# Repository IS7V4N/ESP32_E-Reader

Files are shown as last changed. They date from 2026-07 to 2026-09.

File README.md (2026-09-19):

# ESP32 E-Reader

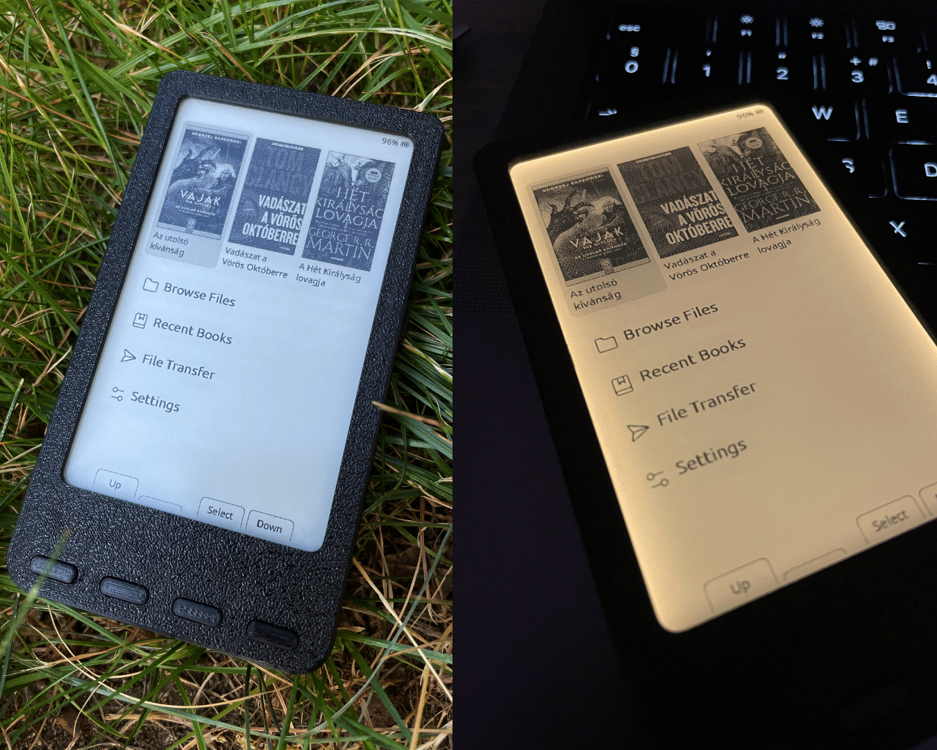
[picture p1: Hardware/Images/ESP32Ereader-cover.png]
ESP32 E-reader


A custom-built e-ink reading device based on the ESP32-C3, designed for everyday use. Built around a 4.2" e-ink display with a frontlight for reading in the dark environment, running a modified version of the [Crosspoint](https://github.com/crosspoint-reader/crosspoint-reader) open-source firmware adapted for custom hardware. The goal was to build a capable, low-cost alternative to commercial e-readers with full control over both hardware and software.

---
## Hardware License

The hardware designs in `/Hardware` are licensed under the
[CERN-OHL-W v2](Hardware/LICENSE).

## Hardware

> Building your own? See the [Build guide](Hardware/docs/Build%20guide.md) for step-by-step assembly instructions.

| Component  | Details |
| --- | --- |
| MCU | ESP32-C3 (4MB flash) |
| Display | Good Display 4.2" grayscale e-ink panel |
| Storage | SD card (books, cache, user settings) |
| Frontlight | TI TPS61169 PWM-controlled LED driver, 15V boost |
| Battery | 700mAh LiPo |
| USB | USB-C (charging + native USB via differential pair) |
| PCB | 4-layer, custom KiCad design (Rev. B) |

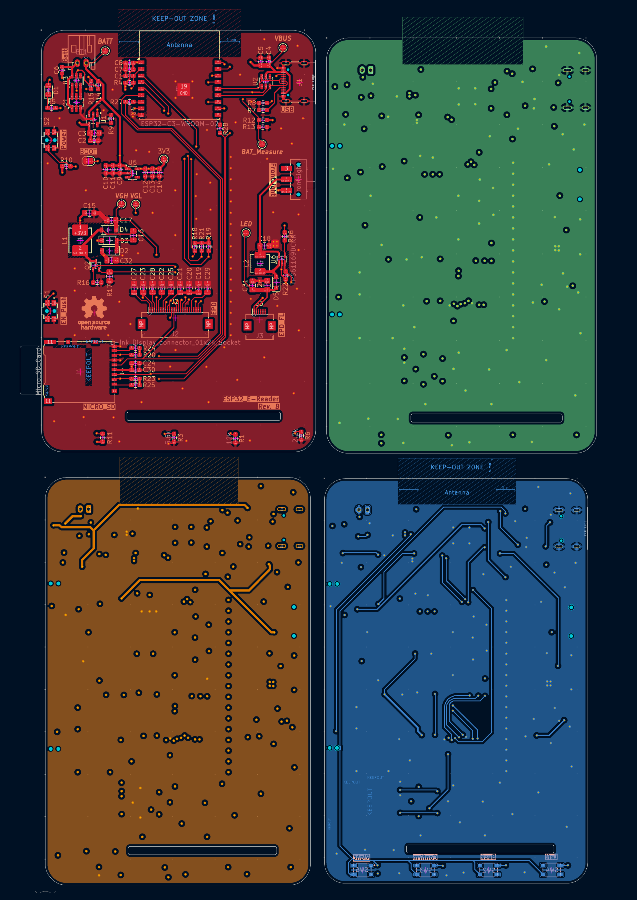
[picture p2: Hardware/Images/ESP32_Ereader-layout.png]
PCB layout


### PCB stack-up

```
F.Cu     — signal
GND      — full ground plane
PWR      — power distribution
B.Cu     — signal
```

Ground pour with stitching vias on both outer layers. EMI-sensitive boost converter traces kept compact.

### Power rails

| Rail | Source | Purpose |
| --- | --- | --- |
| 3.4–4.2V | LiPo battery | System input |
| 3.3V | LDO | ESP32-C3, logic |
| 5V | USB-C input | Charging |
| ±20V | Boost converter | E-ink panel driver |
| 15V | Boost converter (TPS61169) | Frontlight LED driver |

### Power management

Three operating states optimized for battery life:

| State | Description | Wake latency |
| --- | --- | --- |
| Active | Full speed, display updating | — |
| Sleep | Reduced CPU clock, peripherals idle | Fast |
| Deep sleep | µA range consumption, triggered by power button | Slow |

The device enters Sleep automatically after a display update completes. Deep sleep is only used when powered off via the power button.

### Controls

| Button | Function |
| --- | --- |
| Left / Right / Back / Confirm | Context-sensitive navigation (current function shown on display) |
| Power button | Short press: page turn / Long press: power on/off |

---

## Firmware

Based on [Crosspoint Reader](https://github.com/crosspoint-reader/crosspoint-reader) with modifications for custom hardware and 4MB flash constraint.

### What's changed from upstream

- **HalFrontlight** — new HAL driver for PWM-controlled frontlight via TPS61169
- **HalPowerManager** — smaller tweaks
- **HalGPIO** — GPIO, button layout adapted to custom PCB
- **partitions_4mb.csv** — custom partition scheme to fit 4MB flash (replaces upstream 16MB default)
- **platformio.ini** — 4MB build configuration
- **Display refresh** — modified refresh handling for Good Display 4.2" panel compatibility
- **Dictionary** — English → Hungarian word lookup in the EPUB reader (see [Dictionary](#dictionary))

See [`docs/4mb-build/`](Software/crosspoint-reader/docs/4mb-build/) for detailed documentation on the 4MB build process and known issues.

## Dictionary

Long-press **Confirm** (0.5 s) in an EPUB to enter dictionary mode. The four front buttons become a cursor:

| Button (left to right) | Short press  | Long press |
| --- | --- | --- |
| Left | cursor left  | — |
| Back | cursor up | leave dictionary mode |
| Confirm | cursor down  | translate the selected word |
| Right | cursor right | — |

The translation (a few Hungarian words) appears in a popup, any button closes it.

The dictionary is a file on the SD card, `/dict/en-hu.dic` (about 4 MB, 118 000 word forms incl. inflections). It is
built on a PC with [`scripts/build_dict.py`](Software/crosspoint-reader/scripts/build_dict.py) from Wiktionary
(via [kaikki.org](https://kaikki.org)) with [FreeDict eng-hun](https://freedict.org) as a fallback; the script
documents the steps and the file format. Wiktionary data is CC BY-SA 4.0, FreeDict eng-hun is GPL-2.0+.

---

## Repository structure

```
ESP32_E-Reader/
├── Hardware/
│   ├── 3D CAD/                 — enclosure 3D models
│   ├── Bill Of Materials/      — BOM spreadsheets
│   ├── PCB/                    — KiCad project (Rev. B)
│   ├── REV-A/                  — Rev. A schematic/layout reference
│   └── LICENSE                 — CERN-OHL-W v2
├── Datasheets of Components/    — component datasheets (PDF)
└── Software/
    └── crosspoint-reader/       — firmware (fork of Crosspoint Reader)
        ├── src/                 — application source (activities, UI)
        ├── lib/                 — internal libraries (Epub engine, GfxRenderer, HAL, I18n)
        ├── open-x4-sdk/         — Xteink X4 community SDK (submodule)
        ├── docs/                — build docs, file formats, 4mb-build notes
        ├── scripts/             — build/codegen/debugging scripts
        ├── test/                — unit tests
        ├── platformio.ini       — build configuration
        └── LICENSE              — MIT
```

---

## Build

### Requirements

- [PlatformIO](https://platformio.org/)
- ESP32-C3 board with 4MB flash

### Steps

```bash
git clone https://github.com/IS7V4N/ESP32_E-Reader.git
cd ESP32_E-Reader
git submodule update --init --recursive
~/.platformio/penv/bin/pio run -e 4mb -t upload
```

---

## License
`/Hardware` are licensed under the
[CERN-OHL-W v2](Hardware/LICENSE).

Firmware modifications follow the license of the upstream [Crosspoint Reader](https://github.com/crosspoint-reader/crosspoint-reader) project.

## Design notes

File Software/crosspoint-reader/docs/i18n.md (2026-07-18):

# This version of the firmware DOES NOT INCLUDE

# Internationalization (I18N)

This guide explains the multi-language support system in CrossPoint Reader.

## Supported Languages

- English
- French
- German
- Portuguese
- Spanish
- Swedish
- Czech
- Russian
- Ukrainian
- Polish
- Danish
- Turkish

---

## For Developers

### Translation System Architecture

The I18N system uses **per-language YAML files** to maintain translations and a Python script to generate C++ code:

```
lib/I18n/
├── translations/                # One YAML file per language
│   ├── english.yaml
│   ├── spanish.yaml
│   ├── french.yaml
│   └── ...
├── I18n.h
├── I18n.cpp
├── I18nKeys.h                   # Enums (auto-generated)
├── I18nStrings.h                # String array declarations (auto-generated)
└── I18nStrings.cpp              # String array definitions (auto-generated)

scripts/
└── gen_i18n.py                  # Code generator script
```

**Key principle:** All translations are managed in the YAML files under `lib/I18n/translations/`. The Python script generates the necessary C++ code automatically.

---

### YAML File Format

Each language has its own file in `lib/I18n/translations/` (e.g. `spanish.yaml`).

A file looks like this:

```yaml
_language_name: "Español"
_language_code: "ES"
_order: "1"

STR_CROSSPOINT: "CrossPoint"
STR_BOOTING: "BOOTING"
STR_BROWSE_FILES: "Buscar archivos"
```

**Metadata keys** (prefixed with `_`):
- `_language_name` — Native display name shown to the user (e.g. "Français")
- `_language_code` — C++ enum name (e.g. "FR"). Please use the [ISO Code](https://en.wikipedia.org/wiki/List_of_ISO_639_language_codes) of the language. Must be a valid C++ identifier.
- `_order` — Controls the position in the Language enum (English is always 0)

**Rules:**
- Use UTF-8 encoding
- Every line must follow the format: `KEY: "value"`
- Keys must be valid C++ identifiers (uppercase, starts with STR_)
- Keys must be unique within a file
- String values must be quoted
- Use `\n` for newlines, `\\` for literal backslashes, `\"` for literal quotes inside values

---

### Adding New Strings

To add a new translatable string:

#### 1. Edit the English YAML file

Add the key to `lib/I18n/translations/english.yaml`:

```yaml
STR_MY_NEW_STRING: "My New String"
```

Then add translations in each language file. If a key is missing from a
language file, the generator will automatically use the English text as a
fallback (and print a warning).

#### 2. Run the generator script

```bash
python3 scripts/gen_i18n.py lib/I18n/translations lib/I18n/
```

This automatically:
- Fills missing translations from English
- Updates the `StrId` enum in `I18nKeys.h`
- Regenerates all language arrays in `I18nStrings.cpp`

#### 3. Use in code

```cpp
#include <I18n.h>

// Using the tr() macro (recommended)
renderer.drawText(font, x, y, tr(STR_MY_NEW_STRING));

// Using I18N.get() directly
const char* text = I18N.get(StrId::STR_MY_NEW_STRING);
```

**That's it!** No manual array synchronization needed.

---

### Adding a New Language

To add support for a new language (e.g., Italian):

#### 1. Create a new YAML file

Create `lib/I18n/translations/italian.yaml`:

```yaml
_language_name: "Italiano"
_language_code: "IT"
_order: "7"

STR_CROSSPOINT: "CrossPoint"
STR_BOOTING: "AVVIO"
```

You only need to include the strings you have translations for. Missing
keys will fall back to English automatically.

#### 2. Run the generator

```bash
python3 scripts/gen_i18n.py lib/I18n/translations lib/I18n/
```

This automatically updates all necessary code.

---

### Modifying Existing Translations

Simply edit the relevant YAML file and regenerate:

```bash
python3 scripts/gen_i18n.py lib/I18n/translations lib/I18n/
```

---

### UTF-8 Encoding

The YAML files use UTF-8 encoding. Special characters are automatically converted to C++ UTF-8 hex sequences by the generator.

---

### I18N API Reference

```cpp
// === Convenience Macros (Recommended) ===

// tr(id) - Get translated string without StrId:: prefix
const char* text = tr(STR_SETTINGS_TITLE);
renderer.drawText(font, x, y, tr(STR_BROWSE_FILES));
Serial.printf("Status: %s\n", tr(STR_CONNECTED));

// I18N - Shorthand for I18n::getInstance()
I18N.setLanguage(Language::ES);
Language lang = I18N.getLanguage();

// === Full API ===

// Get the singleton instance
I18n& instance = I18n::getInstance();

// Get translated string (three equivalent ways)
const char* text = tr(STR_SETTINGS_TITLE);              // Macro (recommended)
const char* text = I18N.get(StrId::STR_SETTINGS_TITLE);   // Direct call
const char* text = I18N[StrId::STR_SETTINGS_TITLE];       // Operator overload

// Set language
I18N.setLanguage(Language::ES);

// Get current language
Language lang = I18N.getLanguage();

// Save language setting to file
I18N.saveSettings();

// Load language setting from file
I18N.loadSettings();

// Get character set for font subsetting (static method)
const char* chars = I18n::getCharacterSet(Language::FR);
```

---

## File Storage

Language settings are stored in:
```
/.crosspoint/language.bin
```

This file contains:
- Version byte
- Current language selection (1 byte)

---

## Translation Workflow

### For Developers (Adding Features)

1. Add new strings to `lib/I18n/translations/english.yaml`
2. Run `python3 scripts/gen_i18n.py lib/I18n/translations lib/I18n/`
3. Use the new `StrId` in your code
4. Request translations from translators

### For Translators

1. Open the YAML file for your language in `lib/I18n/translations/`
2. Add or update translations using the format `STR_KEY: "translated text"`
3. Keep translations concise (E-ink space constraints)
4. Make sure the file is in UTF-8 encoding
5. Run `python3 scripts/gen_i18n.py lib/I18n/translations lib/I18n/` to verify
6. Test on device or submit for review

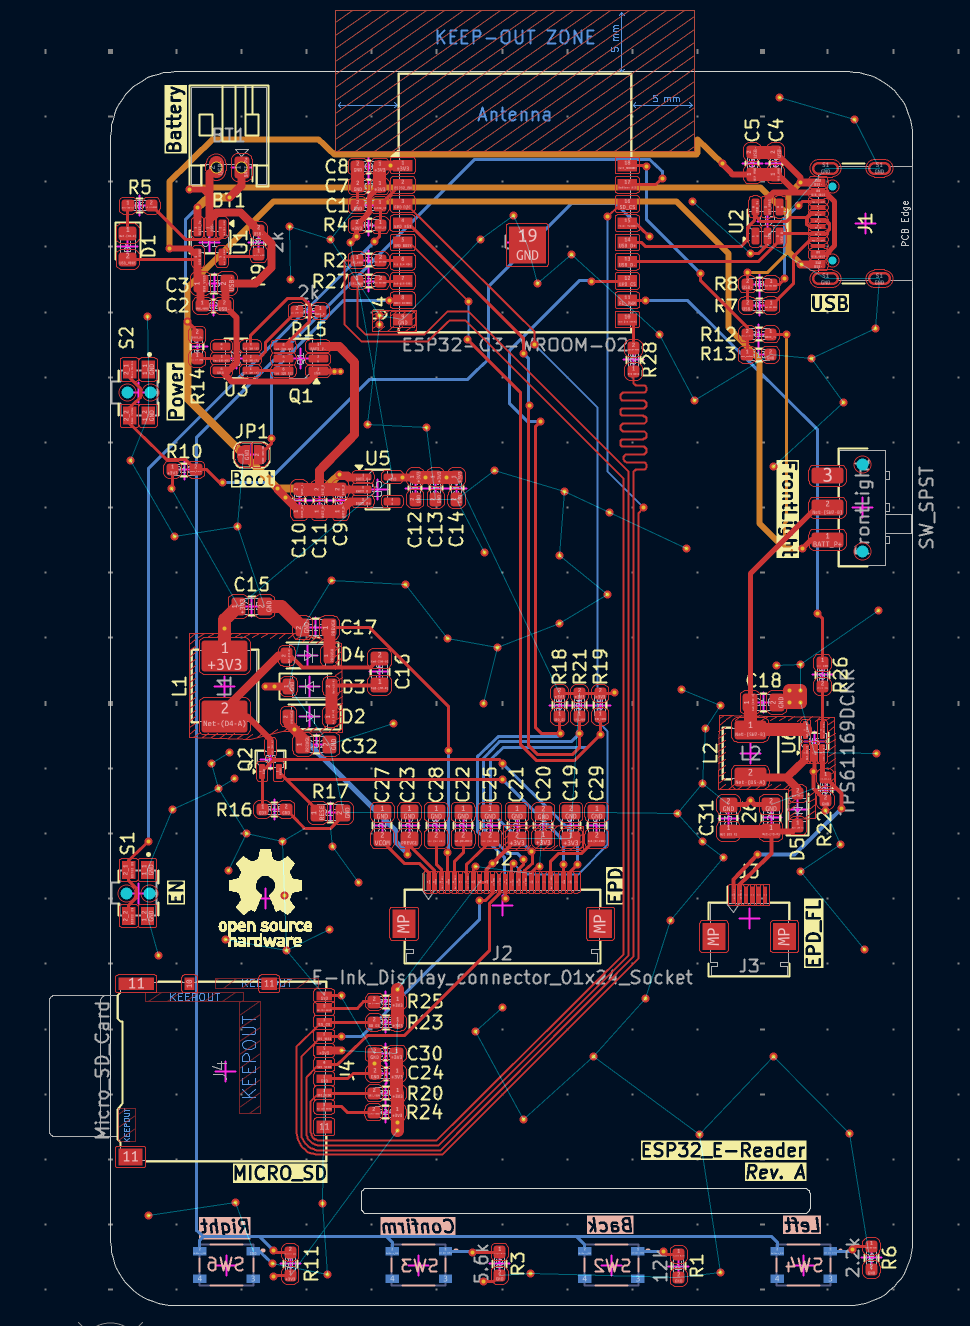
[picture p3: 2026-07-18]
Hardware/REV-A/Rev-A_layout.png

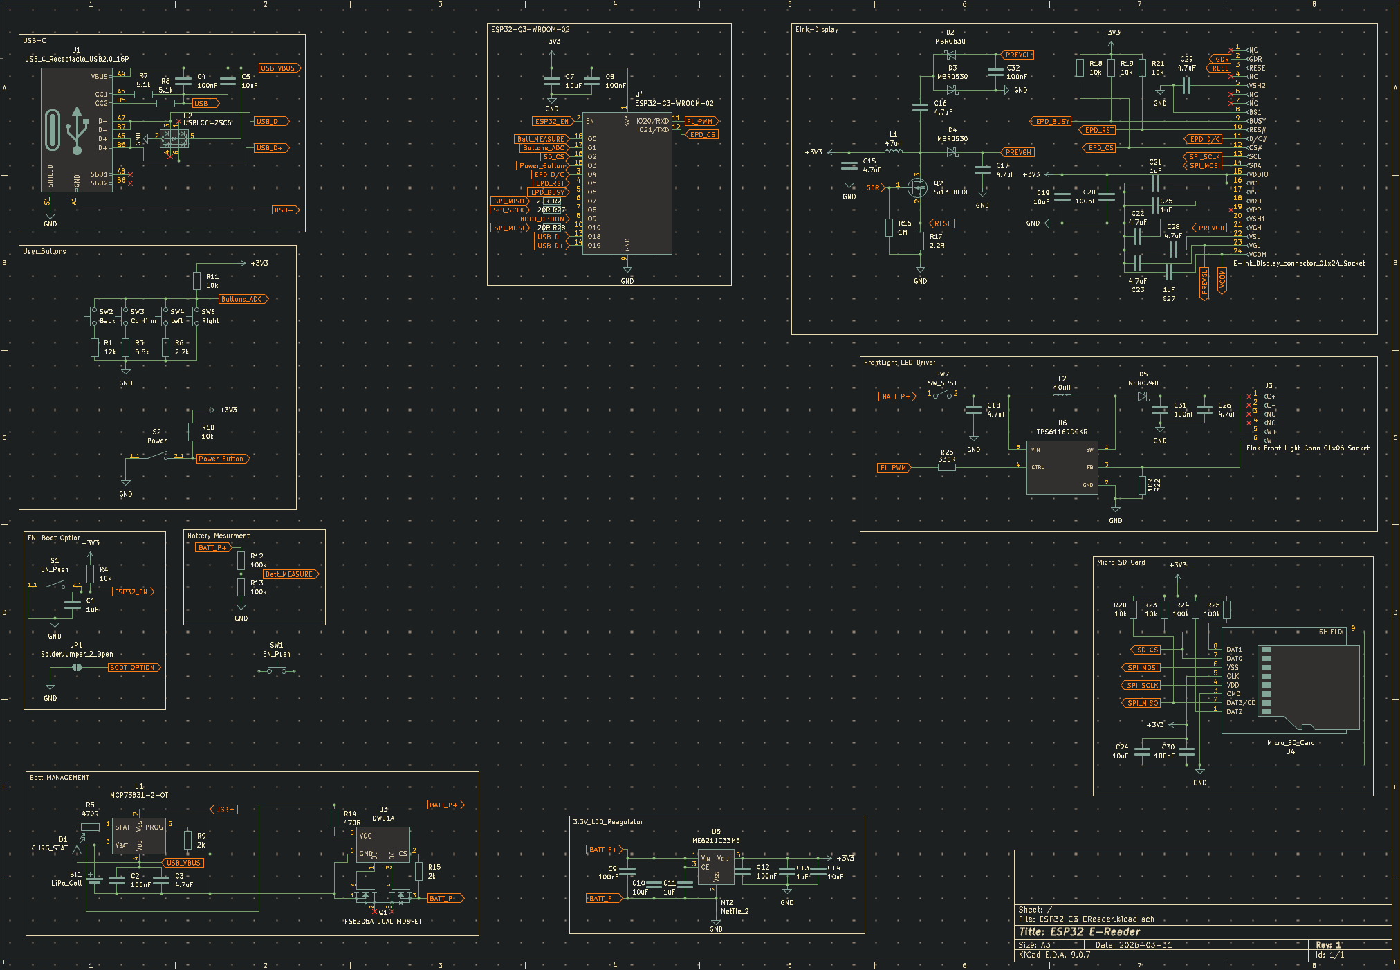
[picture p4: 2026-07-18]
Hardware/REV-A/Rev-A_Schem.png

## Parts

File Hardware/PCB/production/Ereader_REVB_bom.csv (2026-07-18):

Designator | Footprint | Quantity | Value | LCSC Part #
BT1 | JST_PH_S2B-PH-K_1x02_P2.00mm_Horizontal | 1 | Batt
C1, C11, C13 | 0603 | 3 | 1uF
C10, C14, C24, C5, C6, C7 | 0603 | 6 | 10uF
C12, C2, C30, C4, C8, C9 | 0603 | 6 | 100nF
C15, C16, C17, C18, C22, C23, C26, C28, C29, C3 | 0805 | 10 | 4.7uF
C19 | 0805 | 1 | 10uF
C20, C31, C32 | 0805 | 3 | 100nF
C21, C25, C27 | 0805 | 3 | 1uF
D1 | 0805 | 1 | CHRG_STAT
D2, D3, D4 | D_SOD-123 | 3 | MBR0530
D5 | D_SOD-323_HandSoldering | 1 | NSR0240
FRONTLIGHT | SW_SPDT_CK_JS102011SAQN | 1 | EPD_FL
J1 | USB_C_Receptacle_GCT_USB4105-xx-A_16P_TopMnt_Horizontal | 1 | USB
J2 | Mirrored_Hirose_FH12-24S-0.5SH_1x24-1MP_P0.50mm_Horizontal | 1 | E-Ink_Display_connector_01x24_Socket
J3 | XUNPU FPC-05FB-6PH20_1x06-1MP_P0.50mm_Horizontal | 1 | EInk_Front_Light_Conn_01x06_Socket
J4 | microSD_HC_Hirose_DM3AT-SF-PEJM5 | 1 | Micro_SD_Card
L1 | L_Panasonic_PCC-M0540M | 1 | 47uH
L2 | L_Changjiang_FXL0420 | 1 | 10uH
Q1 | SOT-23-6_Handsoldering | 1 | FS8205A_DUAL_MOSFET
Q2 | SOT-323_SC-70 | 1 | Si1308EDL
R1 | 0603 | 1 | 12k
R10, R11, R18, R19, R20, R21, R23, R4 | 0603 | 8 | 10k
R12, R13, R24, R25 | 0603 | 4 | 100k
R14, R5 | 0603 | 2 | 470R
R15 | 0603 | 1 | 2.7k
R16 | 0603 | 1 | 1M
R17 | 0805 | 1 | 2.2R
R22 | 0603 | 1 | 10R
R26 | 0603 | 1 | 330R
R27, R28 | 0603 | 2 | 20R
R3 | 0603 | 1 | 5.6k
R6 | 0603 | 1 | 2.2k
R7, R8 | 0603 | 2 | 5.1k
R9 | 0603 | 1 | 2.5k
S1 | SW_EVQ-P7C01P | 1 | EN_Push
S2 | SW_EVQ-P7C01P | 1 | Power
SW2 | SW_SKRPACE010 | 1 | Back
SW3 | SW_SKRPACE010 | 1 | Confirm
SW4 | SW_SKRPACE010 | 1 | Left
SW6 | SW_SKRPACE010 | 1 | Right
TP1 | TestPoint_Pad_D1.5mm | 1 | BATT
TP2 | TestPoint_Pad_D1.5mm | 1 | 3V3
TP3 | TestPoint_Pad_D1.5mm | 1 | VBUS
TP4 | TestPoint_Pad_D1.5mm | 1 | VGL
TP5 | TestPoint_Pad_D1.5mm | 1 | VGH
TP6 | TestPoint_Pad_D1.5mm | 1 | BAT_Measure
TP7 | TestPoint_Pad_D1.5mm | 1 | LED
U1 | SOT-23-5 | 1 | MCP73831-2-OT
U2 | SOT-23-6 | 1 | USBLC6-2SC6
U3 | SOT-23-6 | 1 | DW01A
U4 | ESP32-C3-WROOM-02 | 1 | ESP32-C3-WROOM-02
U5 | SOT-23-5 | 1 | ME6211C33M5
U6 | SOT-353_SC-70-5 | 1 | TPS61169DCKR

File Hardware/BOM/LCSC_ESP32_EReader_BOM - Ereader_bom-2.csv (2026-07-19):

Designator | Footprint | Quantity | Value | LCSC Part # | Comment
BT1 | JST_PH_S2B-PH-K_1x02_P2.00mm_Horizontal | 1 | LiPo_Cell | C173752
C1, C11, C13 | 603 | 3 | 1uF | C29936
C10, C14, C24, C5, C7 | 603 | 5 | 10uF | C96446
C12, C2, C30, C4, C8, C9 | 603 | 6 | 100nF | C14663
C15, C16, C17, C18, C22, C23, C26, C28, C29, C3 | 805 | 10 | 4.7uF | C1779
C19 | 805 | 1 | 10uF | C3039694
C21, C25, C27 | 805 | 3 | 1uF | C28323
D2, D3, D4 | D_SOD-123 | 3 | MBR0530 | C82046
D5 | D_SOD-323 | 1 | NSR0240 | C152519 | ordered PMEG4005EJ,115 C426868 (because of long lead time)
J2 | Mirrored_Hirose_FH12-24S-0.5SH_1x24-1MP_P0.50mm_Horizontal | 1 | E-Ink_Display_connector_01x24_Socket | C2856831
J3 | XUNPU FPC-05FB-6PH20_1x06-1MP_P0.50mm_Horizontal | 1 | EInk_Front_Light_Conn_01x06_Socket | C2856827
J4 | microSD_HC_Hirose_DM3AT-SF-PEJM5 | 1 | Micro_SD_Card | C114218
L1 | L_Panasonic_PCC-M0540M | 1 | 47uH | C520357
L2 | L_Changjiang_FXL0420 | 1 | 10uH | C520308
Q1 | SOT-23-6_Handsoldering | 1 | FS8205A_DUAL_MOSFET | C2830320
Q2 | SOT-323_SC-70 | 1 | Si1308EDL | C469327
R1 | 603 | 1 | 12k | C114659
R10, R11, R18, R19, R20, R21, R23, R4 | 603 | 8 | 10k | C98220
R12, R13, R24, R25 | 603 | 4 | 100k | C14675
R14, R5 | 603 | 2 | 470R | C114669
R15, R9 | 603 | 2 | 2k | C22975
R16 | 603 | 1 | 1M | C105578
R17 | 805 | 1 | 2.2R | C2907006
R2, R27, R28 | 603 | 3 | 20R | C125758
R22 | 603 | 1 | 10R | C109318
R26 | 603 | 1 | 330R | C105881
R3 | 603 | 1 | 5.6k | C114627
R6 | 603 | 1 | 2.2k | C113303
R7, R8 | 603 | 2 | 5.1k | C105580
S1 | SW_EVQ-P7C01P | 1 | EN_Push | C388883
S2 | SW_EVQ-P7C01P | 1 | Power | C139797
SW2 | SW_SKRPACE010 | 1 | Back | C139797
SW3 | SW_SKRPACE010 | 1 | Confirm | C139797
SW4 | SW_SKRPACE010 | 1 | Left | C139797
SW6 | SW_SKRPACE010 | 1 | Right | C139797
SW7 | SW_SPDT_CK_JS102011SAQN | 1 | SW_SPST | C49023765
U1 | SOT-23-5 | 1 | MCP73831-2-OT | C424093
U2 | SOT-23-6 | 1 | USBLC6-2SC6 | C7519
U3 | SOT-23-6 | 1 | DW01A | C2927799
U4 | ESP32-C3-WROOM-02 | 1 | ESP32-C3-WROOM-02 | C2934560
U5 | SOT-23-5 | 1 | ME6211C33M5 | C82942
U6 | SOT-353_SC-70-5 | 1 | TPS61169DCKR | C71045
 |  | 81

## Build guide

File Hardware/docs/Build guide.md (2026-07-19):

# Build Guide

This guide walks through assembling the ESP32 E-Reader from a bare PCB to a working device: soldering, enclosure printing, firmware flashing, and first boot.

---

## 1. Get the PCB made

Order the PCB from [JLCPCB](https://jlcpcb.com/) using the Gerbers in [`Hardware/PCB/production`](../PCB/production). Components are sourced from [LCSC](https://www.lcsc.com/) — use the ready-to-upload BOM at [`Hardware/BOM/LCSC_ESP32_EReader_BOM`](../BOM/LCSC_ESP32_EReader_BOM%20-%20Ereader_bom-2.csv) for parts ordering, and the interactive BOM at [`Hardware/BOM/BOM for building/ibom.html`](<../BOM/BOM for building/ibom.html>) to locate components on the board during assembly.

You have two options:

- **JLCPCB assembly (SMT)** — JLCPCB can assemble the board for you. This is the easiest route, but you'll still need to hand-solder the battery connector yourself, since the battery isn't part of the assembly service.
- **Self-assembly (reflow)** — order bare PCBs and solder paste/stencil, and reflow the board yourself.

Hand-soldering the whole board with an iron instead of reflow is possible, but the components are small enough that it requires real micro-soldering experience and proper tools (fine-tip iron, flux, hot air for rework). Reflow is strongly recommended unless you're already comfortable at that scale.

---

## 2. Tools and materials

**For assembly (if self-reflowing):**
- Solder paste (used: Sn63Pb37, Mechanic brand)
- Hot plate (100×100 mm) for reflow
- Soldering iron/station — for touch-up and fixing solder bridges
- Solder wire, flux
- Tweezers for component placement
- Multimeter — for continuity/short checks and voltage verification

**For final assembly:**
- A soldering iron (needed even with JLCPCB assembly, to attach the battery connector)
- Some tape, to hold the battery in place during fitting
- A 3D printer, for the enclosure
- A computer, to flash the firmware

No screws or glue are needed — the enclosure is a snap-fit design.

---

## 3. Print the enclosure

The enclosure files are in [`Hardware/3D CAD`](../3D%20CAD).

**Recommended material: PETG.** PLA is not recommended — under direct sunlight (e.g. reading outdoors, or left on a dashboard/windowsill) it can soften or warp due to heat. PETG has better impact and heat resistance, both useful for a handheld device.

---

## 4. Assemble the board

1. Reflow (or have JLCPCB assemble) the main PCB per the BOM above.
2. **Before connecting anything else, inspect the board and check the power rails with a multimeter for shorts.** Do this before the battery is anywhere near the board.
3. Solder on the battery connector. A **BT2 connector** was used on the prototype rather than soldering the battery leads directly to the board — this makes it easy to detach the battery later for storage, transport, or debugging.

> **⚠️ Battery polarity warning:** Double- and triple-check polarity before connecting or soldering the battery. Reversing polarity is destructive — it will very likely damage the board and/or the battery. Verify polarity with a multimeter against the connector footprint silkscreen before touching anything to the battery pads.

4. Once the connector is on, re-check the voltage rails for shorts *again* before actually plugging in the battery.

Backplate removed, showing the battery connector

---

## 5. Flash the firmware

1. Connect the battery.
2. Connect the board to your computer via USB-C.
3. Flash the firmware — see the [main README](../../README.md#build) for the PlatformIO build/upload steps.
4. On first boot, an **SD card error** on screen is expected and normal if no SD card is inserted yet — it's not a fault.

---

## 6. Insert the SD card and boot

1. Insert an SD card (formatted, with your books — see the firmware docs for supported formats) into the slot.
2. Restart the device using the power button on the side: **long-press it twice** — the first press turns the device off, the second turns it back on.
3. If everything is working, you'll see the Crosspoint home menu on screen.

---

## 7. Done

Snap the enclosure shut and start reading.

---

## Troubleshooting / tips

- If the board doesn't power on, re-check the battery polarity and rail voltages before doing anything else — don't leave the battery connected while debugging shorts.
- If you see the SD card error persist after inserting a card, double check the card is formatted correctly and fully seated in the slot.

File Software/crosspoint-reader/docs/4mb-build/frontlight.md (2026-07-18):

# Frontlight

The frontlight is driven by a PWM signal generated via the ESP32-C3's LEDC peripheral. All logic lives in `lib/hal/HalFrontlight.h` and `lib/hal/HalFrontlight.cpp`.

---

## Hardware

| Property | Value |
|---|---|
| GPIO pin | 20 |
| PWM frequency | 10 kHz (LED driver range: 5–100 kHz) |
| PWM resolution  | 8-bit (duty range 0–255) |
| Driver polarity | Active-high (higher duty = brighter) |

GPIO 20 is shared with the USB presence detection line. Because the frontlight repurposes this pin for PWM output, USB connection detection is permanently disabled (`HalGPIO::isUsbConnected()` always returns `false`).

---

## PWM Brightness Mapping

The LED driver is **active-high**: duty 0 = LED off, higher duty = brighter. No signal inversion is applied in software.

The observed working range of the hardware is approximately `[0, 60]` duty counts (8-bit LEDC). Values above ~60 saturate to the same perceived brightness.

The mapping spreads the full 1–100 % user range linearly across `[PWM_DUTY_MIN, PWM_DUTY_MAX]`:

```
if percent == 0:
    duty = 0                                        // constant LOW -> LED off
else:
    duty = PWM_DUTY_MIN
          + (percent - 1) * (PWM_DUTY_MAX - PWM_DUTY_MIN) / 99
```

| Constant | Value | Purpose |
|---|---|---|
| `PWM_DUTY_MIN`  | 1 | Duty for 1 % UI value (dim but stable) |
| `PWM_DUTY_MAX`  | 60 | Duty for 100 % UI value; LED saturates above this |

Both constants are in `lib/hal/HalFrontlight.h` and are the only values that need tuning if the hardware response changes.

| User % | Duty written | Notes |
|---|---|---|
| 0 | 0 | Off |
| 1 | 1 | Minimum visible brightness |
| 10 | 6 | |
| 50 | 30 | |
| 90 | 54 | |
| 100 | 60 | Maximum brightness |

---

## API

All methods are `static`; no instance is required.

### `HalFrontlight::begin(uint8_t brightnessPercent)`

Attaches the LEDC channel to `FRONTLIGHT_PIN` and immediately applies `brightnessPercent`. Called once during firmware boot (`src/main.cpp`) after settings are loaded.

```cpp
HalFrontlight::begin(SETTINGS.frontlightBrightness);
```

Logs `LOG_ERR` and returns early if `ledcAttach()` fails.

### `HalFrontlight::setBrightness(uint8_t percent)`

Updates the duty cycle at runtime. Values above 100 are clamped to 100.

```cpp
HalFrontlight::setBrightness(50);  // duty = 30/255
```

### `HalFrontlight::off()`

Sets duty to 0 immediately. Called in `enterDeepSleep()` before the device enters deep sleep.

```cpp
HalFrontlight::off();
```

---

## Lifecycle Integration

```
Boot
 └─ setup()
     ├─ SETTINGS.loadFromFile()
     └─ HalFrontlight::begin(SETTINGS.frontlightBrightness)   ← apply saved brightness

Main loop
 └─ loop()
     ├─ if (SETTINGS.frontlightBrightness changed)
     │   └─ HalFrontlight::setBrightness(newValue)            ← settings panel change
     └─ double-press detection
         └─ HalFrontlight::setBrightness(0 or savedValue)     ← power button toggle

Deep sleep
 └─ enterDeepSleep()
     └─ HalFrontlight::off()                                  ← turn off before sleep
```

The main loop polls `SETTINGS.frontlightBrightness` against a cached `lastFrontlight` value. There is no interrupt or callback — changes take effect within one loop iteration.

---

## Power Button Double-Press Toggle

A double-press of the power button (two releases within 300 ms) toggles the frontlight between off (0 %) and the currently configured `SETTINGS.frontlightBrightness`.

The toggle state (`frontlightSuppressed`) is tracked as a `static bool` in `loop()`. An explicit change via the settings panel clears the suppressed state and applies the new value directly.

**Lookahead buffering** prevents accidental page turns in `PAGE_TURN` mode:
- The first release is consumed (hidden from activities) and parked for 300 ms.
- If a second release arrives within the window, the frontlight toggles and neither release reaches any activity.
- If the window expires with no second press, the first release is replayed via `gpio.forceRelease()` so the activity processes it normally (with ≤300 ms latency, imperceptible on e-ink).

See `docs/4mb-build/changes/2026-07-18_feat_frontlight-double-press.md` for implementation details.

**Limitations:**
- Not functional when `shortPwrBtn == SLEEP` (any press immediately triggers deep sleep).
- Toggle state does not survive deep sleep.

---

## User Setting

The brightness is persisted as `CrossPointSettings::frontlightBrightness` (`uint8_t`, default `0`).

| Property | Value |
|---|---|
| Setting key | `frontlightBrightness` |
| Range | 0–100 (step 10) |
| Default | 0 (off) |
| UI label | `STR_FRONTLIGHT` |
| Settings page | Display (`STR_CAT_DISPLAY`) |
| Defined in | `src/SettingsList.h`, `src/CrossPointSettings.h` |

---

## Logging

All log messages use the `"FLT"` module tag.

| Condition | Level | Message example |
|---|---|---|
| LEDC attach fails | `LOG_ERR` | `LEDC attach failed on GPIO 20` |
| PWM initialised | `LOG_DBG` | `Frontlight PWM initialised on GPIO 20` |
| Brightness changed | `LOG_DBG` | `Brightness 50% -> duty 30/255` |
| Double-press off | `LOG_DBG` | `Double-press: frontlight off` |
| Double-press restore | `LOG_DBG` | `Double-press: frontlight restored` |

---

## Tuning

Edit `PWM_DUTY_MIN` and `PWM_DUTY_MAX` in `lib/hal/HalFrontlight.h`:

```cpp
static constexpr uint8_t PWM_DUTY_MIN = 1;   // raise if 1% flickers
static constexpr uint8_t PWM_DUTY_MAX = 60;  // raise if 100% seems too dim
```

No other files need to change. The user-facing 0–100 % scale re-maps automatically.

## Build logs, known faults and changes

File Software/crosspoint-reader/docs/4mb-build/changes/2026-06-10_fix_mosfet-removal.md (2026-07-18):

# fix: Battery latch MOSFET kód eltávolítva

**Dátum:** 2026-06-10  
**Típus:** fix  
**Érintett fájl:** `lib/hal/HalPowerManager.cpp` — `startDeepSleep()` metódus

## Módosítás

Eltávolítottuk a GPIO13 battery latch MOSFET vezérlő kódot a `startDeepSleep()` metódusból.

```cpp
// Eltávolított kódblokk:
constexpr gpio_num_t GPIO_SPIWP = GPIO_NUM_13;
gpio_set_direction(GPIO_SPIWP, GPIO_MODE_OUTPUT);
gpio_set_level(GPIO_SPIWP, 0);
esp_sleep_config_gpio_isolate();
gpio_deep_sleep_hold_en();
gpio_hold_en(GPIO_SPIWP);
```

## Ok

A battery latch MOSFET (GPIO13) nincs beépítve a 4MB build hardverre. Ha a kód
mégis futott volna, a GPIO13-at (ami az ESP32-C3 SPI WP / Write Protect lába) OUTPUT
módba és alacsony szintre húzta volna — felesleges, és potenciálisan zavarhatta
az SPI flash kommunikációt.

## Hatás

- A deep sleep továbbra is működik az `esp_deep_sleep_start()` hívással
- A power button wakeup (`esp_deep_sleep_enable_gpio_wakeup`) érintetlen maradt
- **Pozitív mellékhatás:** Az `RTC_NOINIT_ATTR` log ring buffer megőrzi tartalmát
  sleep ciklusok között (a MOSFET az RTC RAM-ot is kikapcsolta volna)

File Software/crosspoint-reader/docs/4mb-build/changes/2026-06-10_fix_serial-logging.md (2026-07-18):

# fix: Serial logging feltétel nélkül indul

**Dátum:** 2026-06-10  
**Típus:** fix  
**Érintett fájl:** `src/main.cpp` (~239. sor)

## Módosítás

A `Serial.begin()` hívás korábban `gpio.isUsbConnected()` feltételhez volt kötve.
Ez a függvény (`lib/hal/HalGPIO.cpp:25-28`) mindig `false`-t ad vissza,
mert a GPIO20 pint az eredeti USB-észlelés céljára tervezték, de a 4MB build
hardveren ezt a pint a frontlight PWM-vezérlés foglalja el.

**Eredmény:** A serial monitor soha nem kapott adatot, a `debugging_monitor.py`
üres kimenetet mutatott.

## Javítás

Eltávolítottuk az `isUsbConnected()` feltételt. A Serial mindig elindul, és legfeljebb
3 másodpercig vár USB host csatlakozásra. Ha nincs host, a boot folytatódik blokkolás nélkül.

**FONTOS — pozícionálás:** A `Serial.begin()` blokkot a `verifyPowerButtonDuration()` UTÁN
kell elhelyezni (a wakeup-reason switch/case után). Ha előtte van, a 3 másodperces
USB-várakozás eltolódást okoz, és a gombnyomás-ellenőrzés mindig `abort`-ot ad vissza
(a gomb már elengedett, mire a kód ideér) → kétszeri gombnyomást igényel a bekapcsoláshoz.

```cpp
// Előtte:
if (gpio.isUsbConnected()) {
  Serial.begin(115200);
  ...
}

// Utána (helyes pozícióban, AFTER verifyPowerButtonDuration()):
Serial.begin(115200);
{
  unsigned long serialStart = millis();
  while (!Serial && (millis() - serialStart) < 3000) {
    delay(10);
  }
}
```

## Ok

A 4MB build hardveren a GPIO20 frontlight PWM-re van kötve, nem USB VBUS észlelésre.
Az eredeti kódban lévő `isUsbConnected()` hívás ezért sosem tér vissza `true`-val.

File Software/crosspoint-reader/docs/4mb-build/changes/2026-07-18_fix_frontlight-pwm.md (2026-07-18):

# fix: Frontlight PWM helyes irány és tartomány

**Dátum:** 2026-07-18  
**Típus:** fix  
**Érintett fájlok:**
- `lib/hal/HalFrontlight.h` — `PWM_DUTY_MIN`, `PWM_DUTY_MAX` konstansok
- `lib/hal/HalFrontlight.cpp` — `setBrightness()` logika

---

## Tünetek

- UI 10–80% között azonos fényerő
- 90%-nál kicsit sötétebb
- 100%-nál teljesen kialszik a frontlight

---

## Gyökérok — két egymástól független hiba

### 1. Invertált PWM irány

Az eredeti kód az `hwDuty = 255 - duty` képlettel megfordította a PWM duty cycle-t, mert a megjegyzés szerint a hardver invertált kimenettel rendelkezik:

```cpp
// RÉGI (hibás):
const uint8_t hwDuty = static_cast<uint8_t>(255u - duty);
ledcWrite(FRONTLIGHT_PIN, hwDuty);
```

A valóságban a LED driver **active-high** (magasabb duty = fényesebb), és nincs szoftveres invertálásra szükség. Az `off()` hívás helyesen írta `0`-ra a duty-t (LED ki), de `setBrightness(100)` szintén `0`-t írt ki az invertálás miatt — ezért kapcsolt ki 100%-nál.

### 2. Hibás tartomány-mapping

```cpp
// RÉGI (hibás):
const uint8_t scaled = (percent * PWM_DUTY_MAX) / 100;
// PWM_DUTY_MAX = 255 → scaled = percent * 2.55
// duty = max(scaled, PWM_DUTY_MIN = 200)
```

Ez azt jelenti, hogy 1–78% esetén `scaled < 200`, ezért mindegyik `duty = 200` értékre kerül → azonos fényerő. Csak 79–100% között volt tényleges eltérés — de az invertálás miatt csökkenő irányban.

---

## Javítás

### `lib/hal/HalFrontlight.h`

```cpp
// RÉGI:
static constexpr uint8_t PWM_DUTY_MIN = 200;
static constexpr uint8_t PWM_DUTY_MAX = 255;

// ÚJ:
static constexpr uint8_t PWM_DUTY_MIN = 1;   // 1% UI értéknél minimális de stabil fény
static constexpr uint8_t PWM_DUTY_MAX = 60;  // LED ~60 duty felett telítésbe megy
```

A valós hardvermérés alapján a LED a `[0, ~60]` duty tartományban reagál; e felett telítésbe megy (azonos fényerő). A `PWM_DUTY_MAX` szükség esetén hangolható.

### `lib/hal/HalFrontlight.cpp` — `setBrightness()`

```cpp
// ÚJ: 1–100% lineárisan leképezve [PWM_DUTY_MIN, PWM_DUTY_MAX]-ra, invertálás nélkül
const uint8_t duty = static_cast<uint8_t>(
    PWM_DUTY_MIN +
    (static_cast<uint16_t>(percent - 1) * (PWM_DUTY_MAX - PWM_DUTY_MIN)) / 99u);
ledcWrite(FRONTLIGHT_PIN, duty);
```

---

## Ellenőrzés

| UI % | duty (0–255) | Várható eredmény |
|---|---|---|
| 0% | 0 | Ki (off) |
| 1% | 1 | Alig látható |
| 50%  | 31 | Közepes fény |
| 100% | 60 | Maximum (telítési pont)|

Serial log (`FLT` prefix): `Brightness 50% -> duty 31/255`

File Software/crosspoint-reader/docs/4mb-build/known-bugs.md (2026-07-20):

# 4MB Build — Ismert bugok

## BUG-001 — Webes fájlátvitel — File Manager tab 403 hiba

**Érintett build:** 4mb
**Első észlelés:** 2026-06-11
**Súlyosság:** Közepes — fájlkezelő tab nem elérhető
**Állapot:** Megoldva (2026-07-20)

### Tünet
A webes fájlátvitel felületen a három tab közül a File Manager tab 403 hibát dob (böngészőben "Not Found" szövegként jelenik meg a `/files` oldalon).

### Gyökérok
A `HomePage.html` mindig mutatja a "File Manager" tabot, de `CROSSPOINT_NO_WEBUI=1` esetén az `/files` route nincs regisztrálva. A kérést a WebDAV handler kapja el (minden GET-re `canHandle()` true), ami 404-et ad vissza, mert `/files` nem létezik az SD kártyán.

### javítási kísérletek (2026-07-18)
- `CrossPointWebServer::handleStatus()`: `hasFileManager` mező hozzáadva a JSON válaszhoz (`true`/`false` a compile-time flag alapján)
- `HomePage.html`: File Manager link alapból rejtett (`display:none`), JS csak akkor mutatja, ha `data.hasFileManager === true`
- Érintett fájlok: `src/network/CrossPointWebServer.cpp:349`, `src/network/html/HomePage.html`

### Végleges javítás (2026-07-20)
A `CROSSPOINT_NO_WEBUI=1` flag eltávolítva a `[env:4mb]`-ből (`platformio.ini`). A flag bevezetésekor becsült 425KB-os megtakarítás téves volt: a FilesPage HTML és a jszip gzip-elve van beágyazva a firmware-be, a tényleges méretnövekedés csak ~84KB (mért: 3 099 795 → 3 183 937 bájt). A 3 125 KB-os (0x320000) factory partícióban így is ~90KB szabad hely marad. A `hasFileManager` flag ezután automatikusan `true`-t jelent, a File Manager tab a `HomePage.html`-en normálisan megjelenik, a `/files` route pedig ténylegesen ki van szolgálva — a fenti workaroundok (rejtett tab) érdemben feleslegessé váltak, de ártalmatlanok, nem lettek visszavonva.
- Érintett fájl: `platformio.ini` (`[env:4mb]` build_flags, a `-D CROSSPOINT_NO_WEBUI=1` sor törölve)

## BUG-002 — Display szöveg elhalványulás / alacsony kontraszt

**Érintett build:** 4mb
**Első észlelés:** 2026-06-10
**Súlyosság:** Közepes — olvashatóságot rontja, de nem crash
**Állapot:**

### Tünet
Könyv megnyitásakor (és lapozáskor) a szöveg halványabban jelenik meg anti-aliasing bekapcsolt állapotban.

### Gyökérok
A `displayGrayBuffer()` (grayscale AA render) után a RED RAM-ot felülírja a `cleanupGrayscaleBuffers()` az MSB grayscale adatokról az eredeti BW tartalomra. Ezután amikor `displayBuffer()` meghívja `grayscaleRevert()`-et (a következő lapozásnál), a revert LUT rossz adatokat lát:
- BW RAM = LSB (grayscale) ✓
- RED RAM = eredeti BW tartalom ✗ (felülírta a `cleanupGrayscaleBuffers`)

A revert LUT a `00` esetet (`BW=0, RED=0`) "nincs változás"-nak értelmezi, tehát a fehér háttérpixelek (mindkettő 0) nem kapnak feszültséget → szürke állapotban maradnak → halványság.

### javítási kísérletek (2026-07-18)
`pagesUntilFullRefresh = 1` beállítása a grayscale display után:
- A következő lapozásnál `displayWithRefreshCycle()` HALF_REFRESH-t végez
- A HALF_REFRESH CTRL1_BYPASS_RED: nem differenciális, minden pixelt a BW RAM alapján B/F-re hajt, függetlenül az előző állapottól
- Érintett fájlok: `EpubReaderActivity.cpp:782`, `TxtReaderActivity.cpp:382`

### Korábbi javítási kísérletek (visszavonva)
- CTRL1_BYPASS_RED / 0xFC / CMD_AUTO_WRITE_RED_RAM módosítások → üres képernyő
- HALF_REFRESH → FULL_REFRESH csere a ReaderUtils.h-ban → vízszintes vonalak

Részletek: `docs/4mb-build/changes/2026-06-10_fix_half-refresh-temperature.md`

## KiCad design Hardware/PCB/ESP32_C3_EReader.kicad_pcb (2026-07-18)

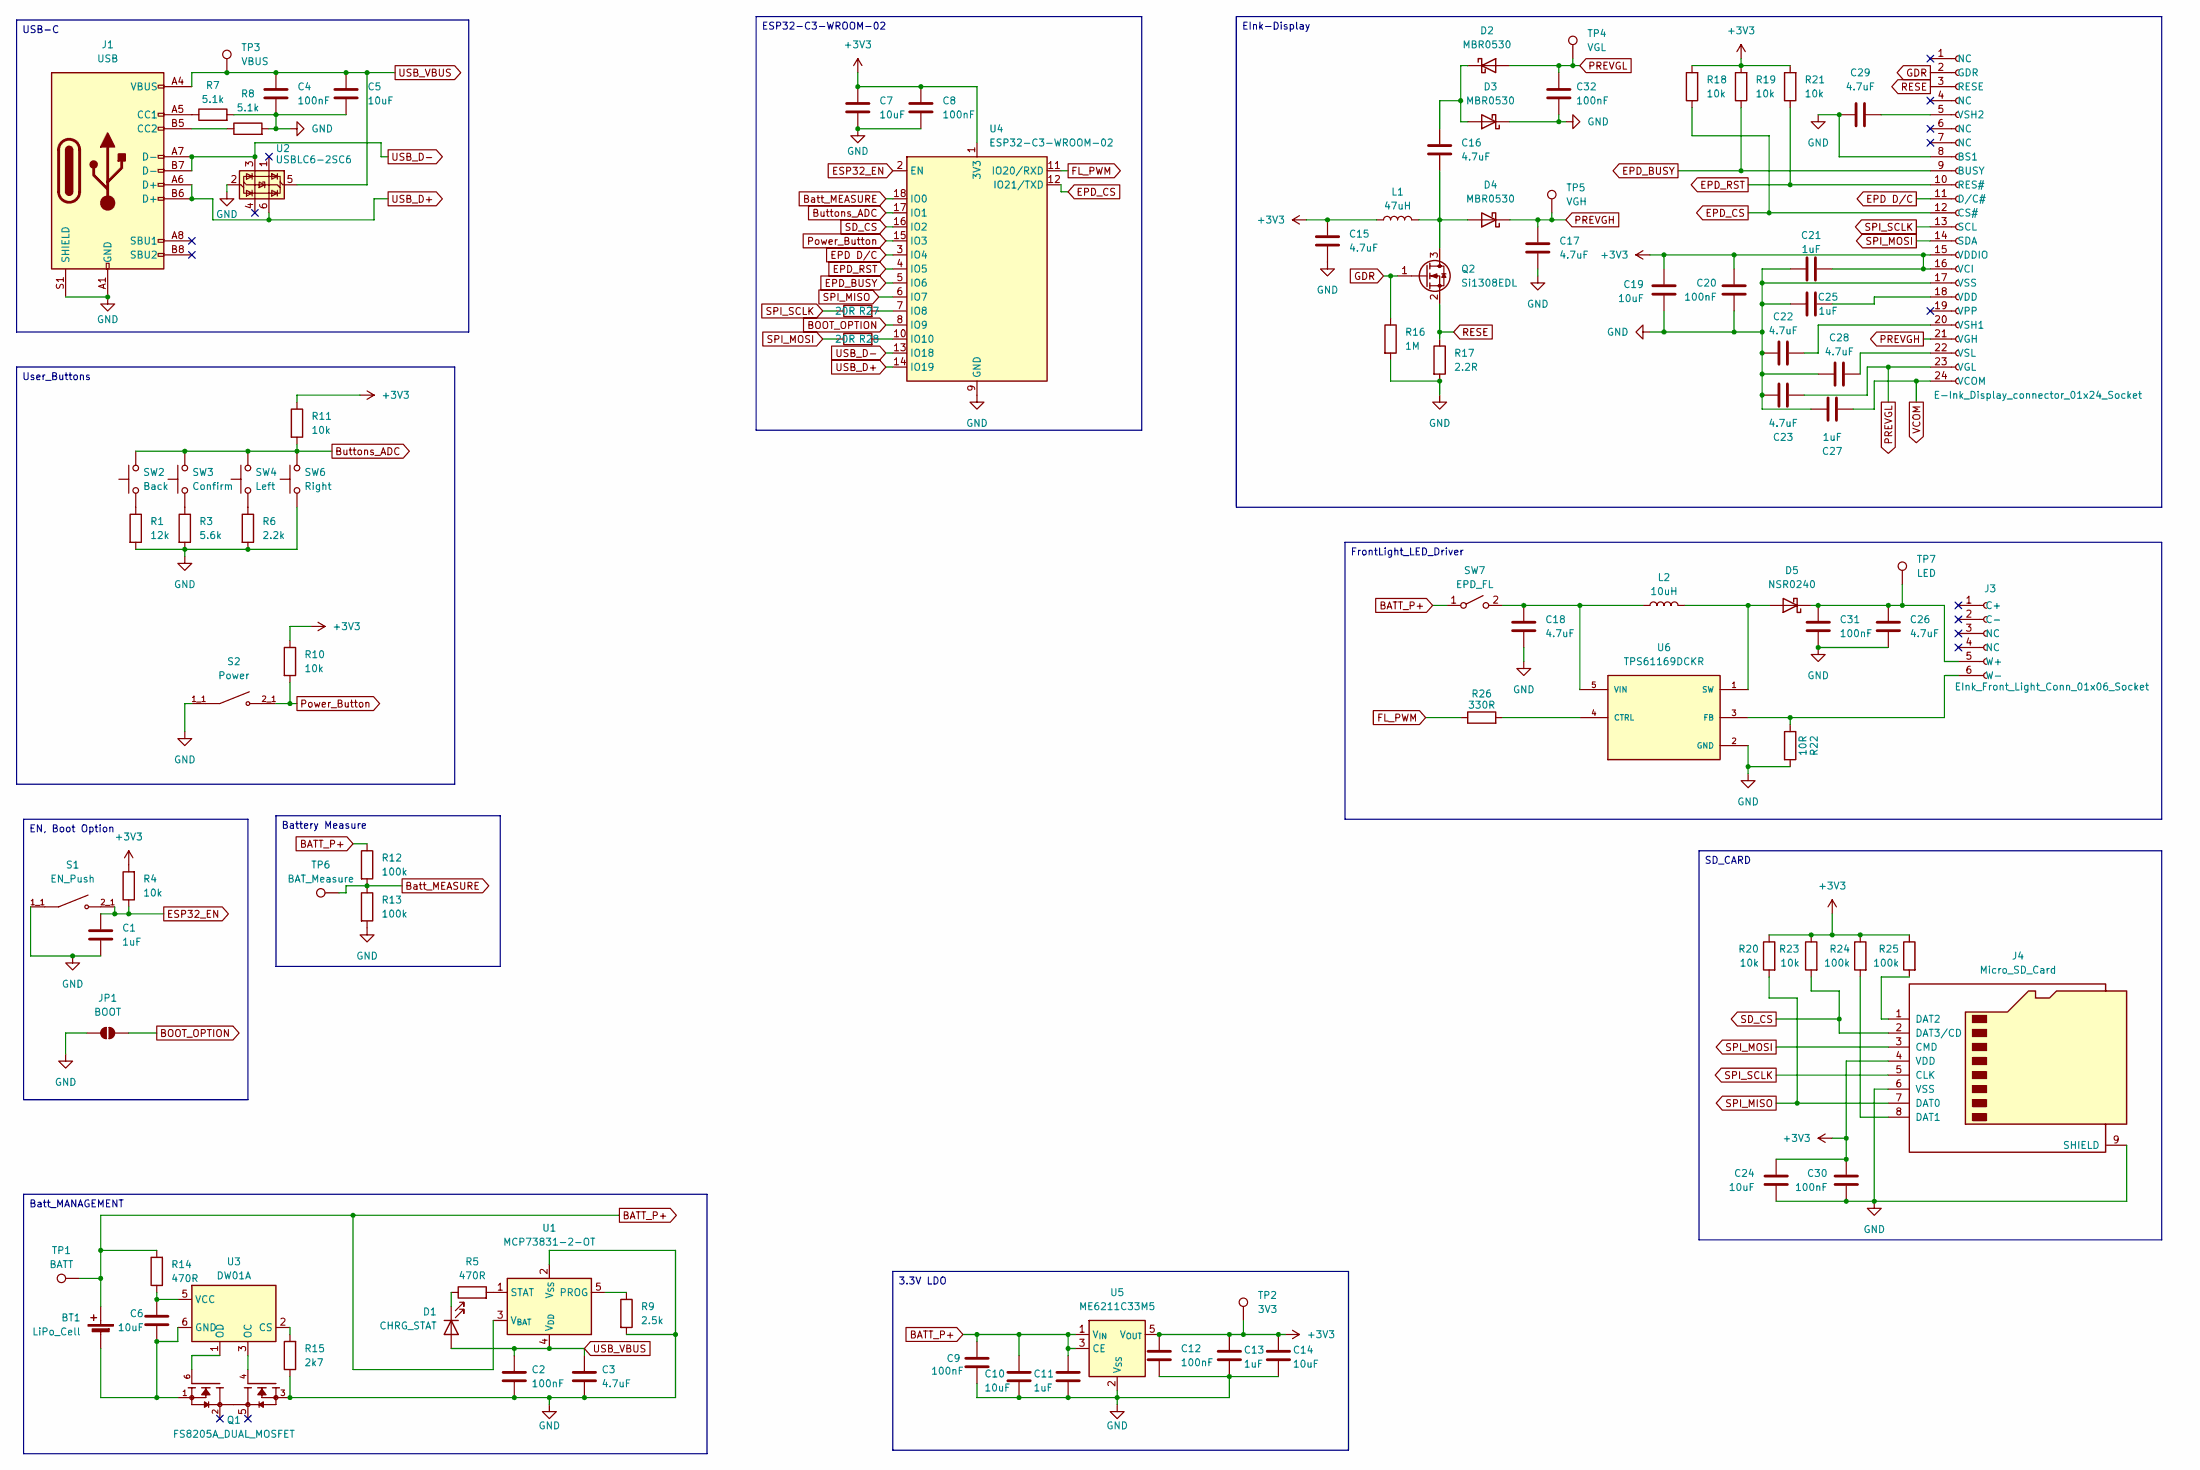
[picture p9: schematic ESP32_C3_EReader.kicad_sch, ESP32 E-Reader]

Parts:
BT1: LiPo_Cell; JST_PH_S2B-PH-K_1x02_P2.00mm_Horizontal
C1, C11, C13: 1uF; C_0603_1608Metric_Pad1.08x0.95mm_HandSolder
C2, C4, C8, C9, C12, C30: 100nF; C_0603_1608Metric_Pad1.08x0.95mm_HandSolder
C3, C15, C16, C17, C18, C22, C23, C26, C28, C29: 4.7uF; C_0805_2012Metric_Pad1.18x1.45mm_HandSolder
C5, C7, C10, C14, C24: 10uF; C_0603_1608Metric_Pad1.08x0.95mm_HandSolder
C6: 10uF; C_0603_1608Metric
C19: 10uF; C_0805_2012Metric_Pad1.18x1.45mm_HandSolder
C20: 100nF; R_0805_2012Metric_Pad1.20x1.40mm_HandSolder
C21, C25, C27: 1uF; C_0805_2012Metric_Pad1.18x1.45mm_HandSolder
C31, C32: 100nF; C_0805_2012Metric_Pad1.18x1.45mm_HandSolder
D1: CHRG_STAT; LED_0805_2012Metric_Pad1.15x1.40mm_HandSolder
D2, D3, D4: MBR0530; D_SOD-123
D5: NSR0240; D_SOD-323_HandSoldering
J1: USB; USB_C_Receptacle_GCT_USB4105-xx-A_16P_TopMnt_Horizontal
J2: E-Ink_Display_connector_01x24_Socket; Mirrored_Hirose_FH12-24S-0.5SH_1x24-1MP_P0.50mm_Horizontal
J3: EInk_Front_Light_Conn_01x06_Socket; XUNPU FPC-05FB-6PH20_1x06-1MP_P0.50mm_Horizontal
J4: Micro_SD_Card; microSD_HC_Hirose_DM3AT-SF-PEJM5
JP1: BOOT; SolderJumper-2_P1.3mm_Open_RoundedPad1.0x1.5mm
L1: 47uH; L_Panasonic_PCC-M0540M
L2: 10uH; L_Changjiang_FXL0420
Q1: FS8205A_DUAL_MOSFET; SOT-23-6_Handsoldering; PARTREV 1.7
Q2: Si1308EDL; SOT-323_SC-70
R1: 12k; R_0603_1608Metric_Pad0.98x0.95mm_HandSolder
R3: 5.6k; R_0603_1608Metric_Pad0.98x0.95mm_HandSolder
R4, R10, R11, R18, R19, R20, R21, R23: 10k; R_0603_1608Metric_Pad0.98x0.95mm_HandSolder
R5, R14: 470R; R_0603_1608Metric_Pad0.98x0.95mm_HandSolder
R6: 2.2k; R_0603_1608Metric_Pad0.98x0.95mm_HandSolder
R7, R8: 5.1k; R_0603_1608Metric_Pad0.98x0.95mm_HandSolder
R9: 2.5k; R_0603_1608Metric_Pad0.98x0.95mm_HandSolder
R12, R13, R24, R25: 100k; R_0603_1608Metric_Pad0.98x0.95mm_HandSolder
R15: 2k7; R_0603_1608Metric_Pad0.98x0.95mm_HandSolder
R16: 1M; R_0603_1608Metric_Pad0.98x0.95mm_HandSolder
R17: 2.2R; R_0805_2012Metric_Pad1.20x1.40mm_HandSolder
R22: 10R; R_0603_1608Metric_Pad0.98x0.95mm_HandSolder
R26: 330R; R_0603_1608Metric_Pad0.98x0.95mm_HandSolder
R27, R28: 20R; R_0603_1608Metric_Pad0.98x0.95mm_HandSolder
S1: EN_Push; SW_EVQ-P7C01P; PARTREV 2022.4
S2: Power; SW_EVQ-P7C01P; PARTREV 2022.4
SW2: Back; SW_SKRPACE010
SW3: Confirm; SW_SKRPACE010
SW4: Left; SW_SKRPACE010
SW6: Right; SW_SKRPACE010
SW7: EPD_FL; SW_SPDT_CK_JS102011SAQN
TP1: BATT; TestPoint_Pad_D1.5mm
TP2: 3V3; TestPoint_Pad_D1.5mm
TP3: VBUS; TestPoint_Pad_D1.5mm
TP4: VGL; TestPoint_Pad_D1.5mm
TP5: VGH; TestPoint_Pad_D1.5mm
TP6: BAT_Measure; TestPoint_Pad_D1.5mm
TP7: LED; TestPoint_Pad_D1.5mm
U1: MCP73831-2-OT; SOT-23-5
U2: USBLC6-2SC6; SOT-23-6
U3: DW01A; SOT-23-6
U4: ESP32-C3-WROOM-02
U5: ME6211C33M5; SOT-23-5
U6: TPS61169DCKR; SOT-353_SC-70-5; PARTREV A

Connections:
+3V3: C7.1, C8.1, C12.1, C13.1, C14.1, C15.1, C19.1, C20.1, C21.2, C24.1, C30.1, J2.15 (VDDIO), J2.16 (VCI), J4.4 (VDD), L1.1, R4.2, R10.1, R11.1, R18.2, R19.2, R20.1, R21.2, R23.1, R24.1, R25.1, TP2.1, U4.1 (3V3), U5.5 (V_{OUT})
BATT_P+: BT1.1 (+), C9.1, C10.1, C11.1, R12.1, R14.2, SW7.1 (A), TP1.1, U1.3 (V_{BAT}), U5.1 (V_{IN}), U5.3 (CE); also elsewhere on the board
BOOT_OPTION: JP1.2 (B), U4.8 (IO9)
Batt_MEASURE: R12.2, R13.1, TP6.1, U4.18 (IO0)
Buttons_ADC: R11.2, SW2.4, SW3.4 (2), SW4.4 (2), SW6.4 (2), U4.17 (IO1)
EPD D/C: J2.11 (D/C#), U4.3 (IO4)
EPD_BUSY: J2.9 (BUSY), R19.1, U4.5 (IO6)
EPD_CS: J2.12 (CS#), R18.1, U4.12 (IO21/TXD)
EPD_RST: J2.10 (RES#), R21.1, U4.4 (IO5)
ESP32_EN: C1.1, R4.1, S1.2_1, S1.2_2, U4.2 (EN)
FL_PWM: R26.1, U4.11 (IO20/RXD)
GDR: J2.2 (GDR), Q2.1 (G), R16.1
unnamed: D1.1 (K), R5.1
unnamed: C16.1, D2.1 (K), D3.2 (A)
unnamed: C16.2, D4.2 (A), L1.2, Q2.3 (D)
unnamed: D5.2 (A), L2.2, U6.1 (SW)
unnamed: C26.1, C31.1, D5.1 (K), J3.5 (W+), TP7.1
unnamed: J1.A5 (CC1), R7.1
unnamed: J1.B5 (CC2), R8.1
unnamed: C25.2, J2.18 (VDD)
unnamed: C22.2, J2.20 (VSH1)
unnamed: C29.2, J2.5 (VSH2)
unnamed: C28.2, J2.22 (VSL)
unnamed: J3.6 (W-), R22.1, U6.3 (FB)
unnamed: J4.8 (DAT1), R24.2
unnamed: J4.1 (DAT2), R25.2
unnamed: Q1.6 (G1), U3.1 (OD)
unnamed: Q1.4 (G2), U3.3 (OC)
unnamed: R1.1, SW2.1
unnamed: R3.1, SW3.1
unnamed: R6.1, SW4.1
unnamed 31: C18.1, L2.1, SW7.2 (B), U6.5 (VIN); also elsewhere on the board
unnamed: R9.1, U1.5 (PROG)
unnamed: R5.2, U1.1 (STAT)
unnamed: R15.2, U3.2 (CS)
unnamed: C6.1, R14.1, U3.5 (VCC)
unnamed: R27.2, U4.7 (IO8)
unnamed: R28.2, U4.10 (IO10)
unnamed: R26.2, U6.4 (CTRL)
PREVGH: C17.1, D4.1 (K), J2.21 (VGH), TP5.1
PREVGL: C23.2, C32.1, D2.2 (A), J2.23 (VGL), TP4.1
Power_Button: R10.2, S2.2_1, S2.2_2, U4.15 (IO3)
RESE: J2.3 (RESE), Q2.2 (S), R17.1
SD_CS: J4.2 (DAT3/CD), R23.2, U4.16 (IO2)
SPI_MISO: J4.7 (DAT0), R20.2, U4.6 (IO7)
SPI_MOSI: J2.14 (SDA), J4.3 (CMD), R28.1
SPI_SCLK: J2.13 (SCL), J4.5 (CLK), R27.1
USB_D+: J1.A6 (D+), J1.B6 (D+), U2.6 (I/O1), U4.14 (IO19)
USB_D-: J1.A7 (D-), J1.B7 (D-), U2.3 (I/O2), U4.13 (IO18)
USB_VBUS: C2.1, C3.1, C4.1, C5.1, D1.2 (A), J1.A4 (VBUS), J1.A9 (VBUS), J1.B4 (VBUS), J1.B9 (VBUS), TP3.1, U1.4 (V_{DD}), U2.5 (VBUS)
VCOM: C27.2, J2.24 (VCOM)

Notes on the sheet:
EN, Boot Option
3.3V LDO
EInk-Display
USB-C
SD_CARD
Batt_MANAGEMENT
User_Buttons
FrontLight_LED_Driver
Battery Measure
ESP32-C3-WROOM-02

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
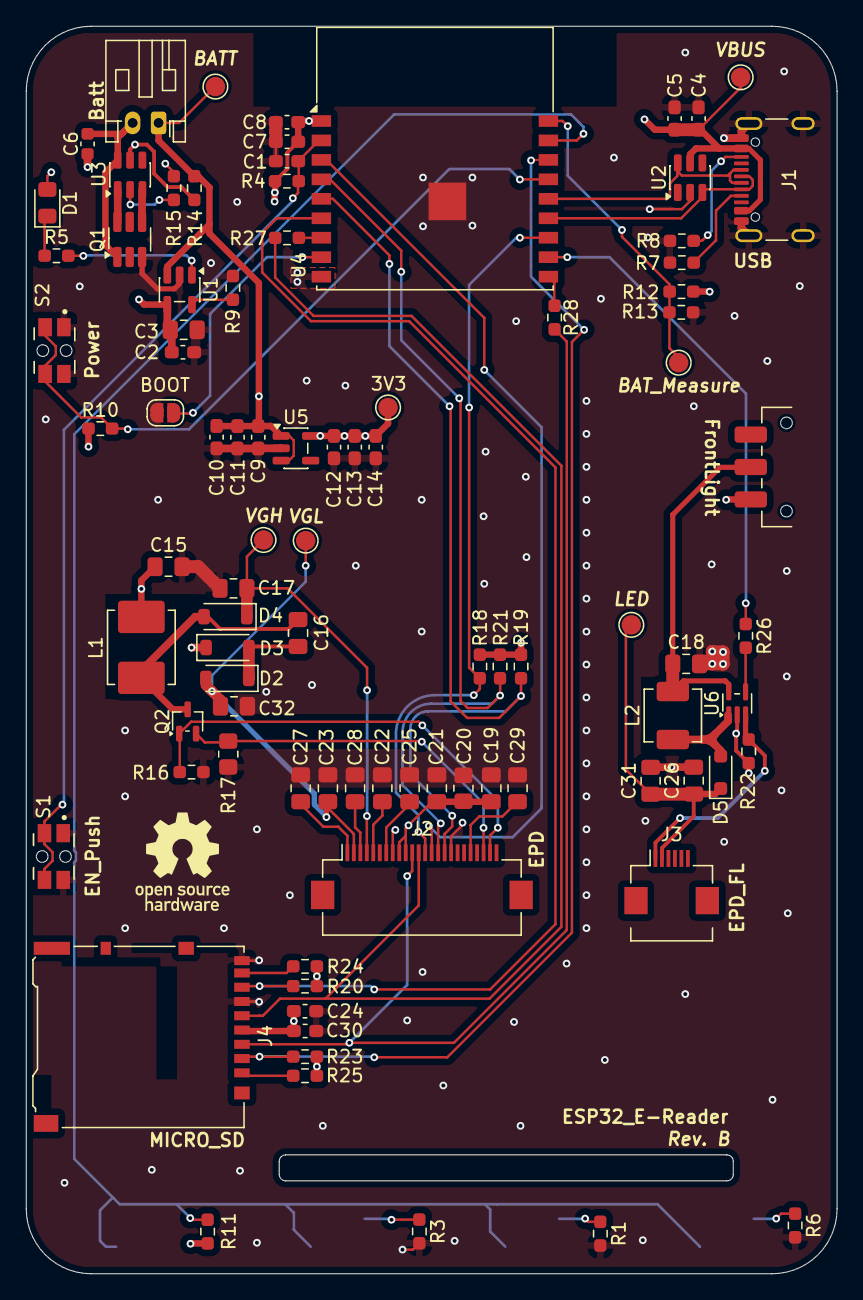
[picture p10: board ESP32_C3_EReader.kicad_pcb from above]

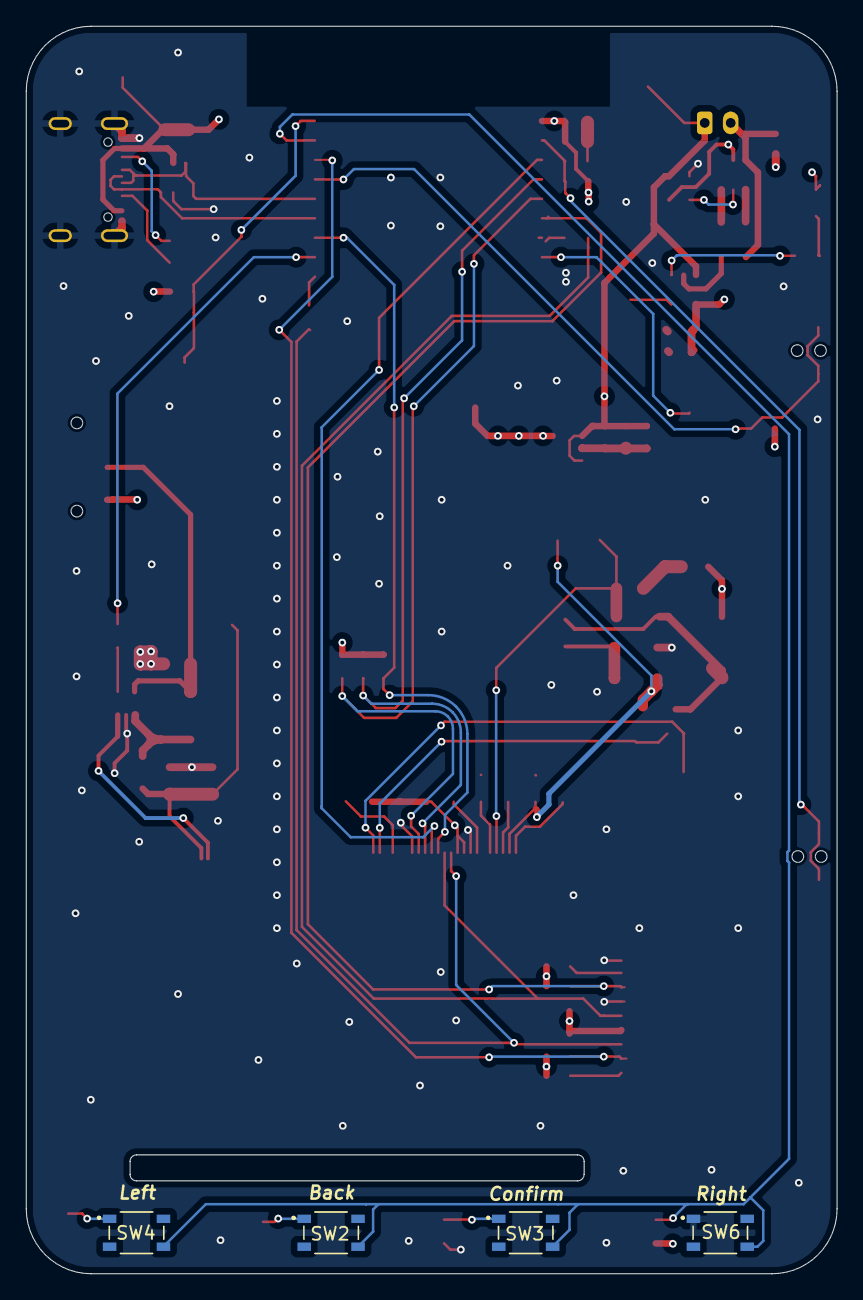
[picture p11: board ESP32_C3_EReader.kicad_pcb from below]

Board: 4 copper layers, 62.5 x 96.2 mm, 94 parts (4 on the bottom side), 53 nets.

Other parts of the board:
FrontLight: EPD_FL; SW_SPDT_CK_JS102011SAQN

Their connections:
BATT_P+: FrontLight.1 (A); also elsewhere on the board
unnamed 31: FrontLight.2 (B); also elsewhere on the board

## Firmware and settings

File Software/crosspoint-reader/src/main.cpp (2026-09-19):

#include <Arduino.h>
#include <Epub.h>
#include <FontCacheManager.h>
#include <FontDecompressor.h>
#include <GfxRenderer.h>
#include <HalDisplay.h>
#include <HalFrontlight.h>
#include <HalGPIO.h>
#include <HalPowerManager.h>
#include <HalStorage.h>
#include <HalSystem.h>
#include <I18n.h>
#include <Logging.h>
#include <SPI.h>
#include <builtinFonts/all.h>

#include <cstring>

#include "CrossPointSettings.h"
#include "CrossPointState.h"
#include "KOReaderCredentialStore.h"
#include "MappedInputManager.h"
#include "ReadingStatsStore.h"
#include "RecentBooksStore.h"
#include "activities/Activity.h"
#include "activities/ActivityManager.h"
#include "components/UITheme.h"
#include "fontIds.h"
#include "util/ButtonNavigator.h"

HalDisplay display;
HalGPIO gpio;
MappedInputManager mappedInputManager(gpio);
GfxRenderer renderer(display);
ActivityManager activityManager(renderer, mappedInputManager);
FontDecompressor fontDecompressor;
FontCacheManager fontCacheManager(renderer.getFontMap());

// Fonts
EpdFont bookerly14RegularFont(&bookerly_14_regular);
EpdFont bookerly14BoldFont(&bookerly_14_bold);
EpdFont bookerly14ItalicFont(&bookerly_14_italic);
EpdFont bookerly14BoldItalicFont(&bookerly_14_bolditalic);
EpdFontFamily bookerly14FontFamily(&bookerly14RegularFont, &bookerly14BoldFont, &bookerly14ItalicFont,
                                   &bookerly14BoldItalicFont);
#ifndef OMIT_FONTS
EpdFont bookerly12RegularFont(&bookerly_12_regular);
EpdFont bookerly12BoldFont(&bookerly_12_bold);
EpdFont bookerly12ItalicFont(&bookerly_12_italic);
EpdFont bookerly12BoldItalicFont(&bookerly_12_bolditalic);
EpdFontFamily bookerly12FontFamily(&bookerly12RegularFont, &bookerly12BoldFont, &bookerly12ItalicFont,
                                   &bookerly12BoldItalicFont);
EpdFont bookerly16RegularFont(&bookerly_16_regular);
EpdFont bookerly16BoldFont(&bookerly_16_bold);
EpdFont bookerly16ItalicFont(&bookerly_16_italic);
EpdFont bookerly16BoldItalicFont(&bookerly_16_bolditalic);
EpdFontFamily bookerly16FontFamily(&bookerly16RegularFont, &bookerly16BoldFont, &bookerly16ItalicFont,
                                   &bookerly16BoldItalicFont);
EpdFont bookerly18RegularFont(&bookerly_18_regular);
EpdFont bookerly18BoldFont(&bookerly_18_bold);
EpdFont bookerly18ItalicFont(&bookerly_18_italic);
EpdFont bookerly18BoldItalicFont(&bookerly_18_bolditalic);
EpdFontFamily bookerly18FontFamily(&bookerly18RegularFont, &bookerly18BoldFont, &bookerly18ItalicFont,
                                   &bookerly18BoldItalicFont);

EpdFont notosans12RegularFont(&notosans_12_regular);
EpdFont notosans12BoldFont(&notosans_12_bold);
EpdFont notosans12ItalicFont(&notosans_12_italic);
EpdFont notosans12BoldItalicFont(&notosans_12_bolditalic);
EpdFontFamily notosans12FontFamily(&notosans12RegularFont, &notosans12BoldFont, &notosans12ItalicFont,
                                   &notosans12BoldItalicFont);
EpdFont notosans14RegularFont(&notosans_14_regular);
EpdFont notosans14BoldFont(&notosans_14_bold);
EpdFont notosans14ItalicFont(&notosans_14_italic);
EpdFont notosans14BoldItalicFont(&notosans_14_bolditalic);
EpdFontFamily notosans14FontFamily(&notosans14RegularFont, &notosans14BoldFont, &notosans14ItalicFont,
                                   &notosans14BoldItalicFont);
EpdFont notosans16RegularFont(&notosans_16_regular);
EpdFont notosans16BoldFont(&notosans_16_bold);
EpdFont notosans16ItalicFont(&notosans_16_italic);
EpdFont notosans16BoldItalicFont(&notosans_16_bolditalic);
EpdFontFamily notosans16FontFamily(&notosans16RegularFont, &notosans16BoldFont, &notosans16ItalicFont,
                                   &notosans16BoldItalicFont);
EpdFont notosans18RegularFont(&notosans_18_regular);
EpdFont notosans18BoldFont(&notosans_18_bold);
EpdFont notosans18ItalicFont(&notosans_18_italic);
EpdFont notosans18BoldItalicFont(&notosans_18_bolditalic);
EpdFontFamily notosans18FontFamily(&notosans18RegularFont, &notosans18BoldFont, &notosans18ItalicFont,
                                   &notosans18BoldItalicFont);

EpdFont opendyslexic8RegularFont(&opendyslexic_8_regular);
EpdFont opendyslexic8BoldFont(&opendyslexic_8_bold);
EpdFont opendyslexic8ItalicFont(&opendyslexic_8_italic);
EpdFont opendyslexic8BoldItalicFont(&opendyslexic_8_bolditalic);
EpdFontFamily opendyslexic8FontFamily(&opendyslexic8RegularFont, &opendyslexic8BoldFont, &opendyslexic8ItalicFont,
                                      &opendyslexic8BoldItalicFont);
EpdFont opendyslexic10RegularFont(&opendyslexic_10_regular);
EpdFont opendyslexic10BoldFont(&opendyslexic_10_bold);
EpdFont opendyslexic10ItalicFont(&opendyslexic_10_italic);
EpdFont opendyslexic10BoldItalicFont(&opendyslexic_10_bolditalic);
EpdFontFamily opendyslexic10FontFamily(&opendyslexic10RegularFont, &opendyslexic10BoldFont, &opendyslexic10ItalicFont,
                                       &opendyslexic10BoldItalicFont);
EpdFont opendyslexic12RegularFont(&opendyslexic_12_regular);
EpdFont opendyslexic12BoldFont(&opendyslexic_12_bold);
EpdFont opendyslexic12ItalicFont(&opendyslexic_12_italic);
EpdFont opendyslexic12BoldItalicFont(&opendyslexic_12_bolditalic);
EpdFontFamily opendyslexic12FontFamily(&opendyslexic12RegularFont, &opendyslexic12BoldFont, &opendyslexic12ItalicFont,
                                       &opendyslexic12BoldItalicFont);
EpdFont opendyslexic14RegularFont(&opendyslexic_14_regular);
EpdFont opendyslexic14BoldFont(&opendyslexic_14_bold);
EpdFont opendyslexic14ItalicFont(&opendyslexic_14_italic);
EpdFont opendyslexic14BoldItalicFont(&opendyslexic_14_bolditalic);
EpdFontFamily opendyslexic14FontFamily(&opendyslexic14RegularFont, &opendyslexic14BoldFont, &opendyslexic14ItalicFont,
                                       &opendyslexic14BoldItalicFont);
#elif defined(INCLUDE_EXTRA_READER_FONTS)
EpdFont notosans14RegularFont(&notosans_14_regular);
EpdFont notosans14BoldFont(&notosans_14_bold);
EpdFont notosans14ItalicFont(&notosans_14_italic);
EpdFont notosans14BoldItalicFont(&notosans_14_bolditalic);
EpdFontFamily notosans14FontFamily(&notosans14RegularFont, &notosans14BoldFont, &notosans14ItalicFont,
                                   &notosans14BoldItalicFont);
EpdFont opendyslexic14RegularFont(&opendyslexic_14_regular);
EpdFont opendyslexic14BoldFont(&opendyslexic_14_bold);
EpdFont opendyslexic14ItalicFont(&opendyslexic_14_italic);
EpdFont opendyslexic14BoldItalicFont(&opendyslexic_14_bolditalic);
EpdFontFamily opendyslexic14FontFamily(&opendyslexic14RegularFont, &opendyslexic14BoldFont,
                                       &opendyslexic14ItalicFont, &opendyslexic14BoldItalicFont);
#endif  // OMIT_FONTS / INCLUDE_EXTRA_READER_FONTS

EpdFont smallFont(&notosans_8_regular);
EpdFontFamily smallFontFamily(&smallFont);

EpdFont ui10RegularFont(&ubuntu_10_regular);
EpdFont ui10BoldFont(&ubuntu_10_bold);
EpdFontFamily ui10FontFamily(&ui10RegularFont, &ui10BoldFont);

EpdFont ui12RegularFont(&ubuntu_12_regular);
EpdFont ui12BoldFont(&ubuntu_12_bold);
EpdFontFamily ui12FontFamily(&ui12RegularFont, &ui12BoldFont);

// measurement of power button press duration calibration value
unsigned long t1 = 0;
unsigned long t2 = 0;

// Verify power button press duration on wake-up from deep sleep
// Pre-condition: isWakeupByPowerButton() == true
void verifyPowerButtonDuration() {
  if (SETTINGS.shortPwrBtn == CrossPointSettings::SHORT_PWRBTN::SLEEP) {
    // Fast path for short press
    // Needed because inputManager.isPressed() may take up to ~500ms to return the correct state
    return;
  }

  // Give the user up to 1000ms to start holding the power button, and must hold for SETTINGS.getPowerButtonDuration()
  const auto start = millis();
  bool abort = false;
  // Subtract the current time, because inputManager only starts counting the HeldTime from the first update()
  // This way, we remove the time we already took to reach here from the duration,
  // assuming the button was held until now from millis()==0 (i.e. device start time).
  const uint16_t calibration = start;
  const uint16_t calibratedPressDuration =
      (calibration < SETTINGS.getPowerButtonDuration()) ? SETTINGS.getPowerButtonDuration() - calibration : 1;

  gpio.update();
  // Needed because inputManager.isPressed() may take up to ~500ms to return the correct state
  while (!gpio.isPressed(HalGPIO::BTN_POWER) && millis() - start < 1000) {
    delay(10);  // only wait 10ms each iteration to not delay too much in case of short configured duration.
    gpio.update();
  }

  t2 = millis();
  if (gpio.isPressed(HalGPIO::BTN_POWER)) {
    do {
      delay(10);
      gpio.update();
    } while (gpio.isPressed(HalGPIO::BTN_POWER) && gpio.getHeldTime() < calibratedPressDuration);
    abort = gpio.getHeldTime() < calibratedPressDuration;
  } else {
    abort = true;
  }

  if (abort) {
    // Button released too early. Returning to sleep.
    // IMPORTANT: Re-arm the wakeup trigger before sleeping again
    powerManager.startDeepSleep(gpio);
  }
}

void waitForPowerRelease() {
  gpio.update();
  while (gpio.isPressed(HalGPIO::BTN_POWER)) {
    delay(50);
    gpio.update();
  }
}

// Enter deep sleep mode
void enterDeepSleep() {
  HalPowerManager::Lock powerLock;  // Ensure we are at normal CPU frequency for sleep preparation
  HalFrontlight::off();
  APP_STATE.lastSleepFromReader = activityManager.isReaderActivity();
  APP_STATE.saveToFile();

  activityManager.goToSleep();

  display.deepSleep();
  LOG_DBG("MAIN", "Power button press calibration value: %lu ms", t2 - t1);
  LOG_DBG("MAIN", "Entering deep sleep");

  powerManager.startDeepSleep(gpio);
}

void setupDisplayAndFonts() {
  display.begin();
  renderer.begin();
  activityManager.begin();
  LOG_DBG("MAIN", "Display initialized");

  // Initialize font decompressor for compressed reader fonts
  if (!fontDecompressor.init()) {
    LOG_ERR("MAIN", "Font decompressor init failed");
  }
  fontCacheManager.setFontDecompressor(&fontDecompressor);
  renderer.setFontCacheManager(&fontCacheManager);
  renderer.insertFont(BOOKERLY_14_FONT_ID, bookerly14FontFamily);
#if !defined(OMIT_FONTS)
  renderer.insertFont(BOOKERLY_12_FONT_ID, bookerly12FontFamily);
  renderer.insertFont(BOOKERLY_16_FONT_ID, bookerly16FontFamily);
  renderer.insertFont(BOOKERLY_18_FONT_ID, bookerly18FontFamily);

  renderer.insertFont(NOTOSANS_12_FONT_ID, notosans12FontFamily);
  renderer.insertFont(NOTOSANS_14_FONT_ID, notosans14FontFamily);
  renderer.insertFont(NOTOSANS_16_FONT_ID, notosans16FontFamily);
  renderer.insertFont(NOTOSANS_18_FONT_ID, notosans18FontFamily);
  renderer.insertFont(OPENDYSLEXIC_8_FONT_ID, opendyslexic8FontFamily);
  renderer.insertFont(OPENDYSLEXIC_10_FONT_ID, opendyslexic10FontFamily);
  renderer.insertFont(OPENDYSLEXIC_12_FONT_ID, opendyslexic12FontFamily);
  renderer.insertFont(OPENDYSLEXIC_14_FONT_ID, opendyslexic14FontFamily);
#elif defined(INCLUDE_EXTRA_READER_FONTS)
  renderer.insertFont(NOTOSANS_14_FONT_ID, notosans14FontFamily);
  renderer.insertFont(OPENDYSLEXIC_14_FONT_ID, opendyslexic14FontFamily);
#endif  // OMIT_FONTS / INCLUDE_EXTRA_READER_FONTS
  renderer.insertFont(UI_10_FONT_ID, ui10FontFamily);
  renderer.insertFont(UI_12_FONT_ID, ui12FontFamily);
  renderer.insertFont(SMALL_FONT_ID, smallFontFamily);
  LOG_DBG("MAIN", "Fonts setup");
}

void setup() {
  t1 = millis();

  HalSystem::begin();
  gpio.begin();
  powerManager.begin();

  // SD Card Initialization
  // We need 6 open files concurrently when parsing a new chapter
  if (!Storage.begin()) {
    LOG_ERR("MAIN", "SD card initialization failed");
    setupDisplayAndFonts();
    activityManager.goToFullScreenMessage("SD card error", EpdFontFamily::BOLD);
    return;
  }

  HalSystem::checkPanic();
  HalSystem::clearPanic();  // TODO: move this to an activity when we have one to display the panic info

  SETTINGS.loadFromFile();
  I18N.loadSettings();
  KOREADER_STORE.loadFromFile();
  UITheme::getInstance().reload();
  ButtonNavigator::setMappedInputManager(mappedInputManager);

  // Initialise frontlight PWM and apply saved brightness
  HalFrontlight::begin(SETTINGS.frontlightBrightness);

  switch (gpio.getWakeupReason()) {
    case HalGPIO::WakeupReason::PowerButton:
      // For normal wakeups, verify power button press duration
      LOG_DBG("MAIN", "Verifying power button press duration");
      verifyPowerButtonDuration();
      break;
    case HalGPIO::WakeupReason::AfterUSBPower:
      // If USB power caused a cold boot, go back to sleep
      LOG_DBG("MAIN", "Wakeup reason: After USB Power");
      powerManager.startDeepSleep(gpio);
      break;
    case HalGPIO::WakeupReason::AfterFlash:
      // After flashing, just proceed to boot
    case HalGPIO::WakeupReason::Other:
    default:
      break;
  }

  // Serial init intentionally placed here, after verifyPowerButtonDuration(), to avoid timing interference:
  // a 3-second USB-host wait before the power button check caused the button to be released before the
  // check ran, triggering an immediate return to sleep on every first press.
  Serial.begin(115200);
  {
    unsigned long serialStart = millis();
    while (!Serial && (millis() - serialStart) < 3000) {
      delay(10);
    }
  }

  LOG_DBG("MAIN", "Starting CrossPoint version " CROSSPOINT_VERSION);

  setupDisplayAndFonts();

  activityManager.goToBoot();

  APP_STATE.loadFromFile();
  RECENT_BOOKS.loadFromFile();
  READING_STATS.loadFromFile();

  // Boot to home screen if no book is open, last sleep was not from reader, back button is held, or reader activity
  // crashed (indicated by readerActivityLoadCount > 0)
  if (APP_STATE.openEpubPath.empty() || !APP_STATE.lastSleepFromReader ||
      mappedInputManager.isPressed(MappedInputManager::Button::Back) || APP_STATE.readerActivityLoadCount > 0) {
    activityManager.goHome();
  } else {
    // Clear app state to avoid getting into a boot loop if the epub doesn't load
    const auto path = APP_STATE.openEpubPath;
    APP_STATE.openEpubPath = "";
    APP_STATE.readerActivityLoadCount++;
    APP_STATE.saveToFile();
    activityManager.goToReader(path);
  }

  // Ensure we're not still holding the power button before leaving setup
  waitForPowerRelease();
}

void loop() {
  static unsigned long maxLoopDuration = 0;
  const unsigned long loopStartTime = millis();
  static unsigned long lastMemPrint = 0;

  gpio.update();

  renderer.setFadingFix(SETTINGS.fadingFix);

  // Apply frontlight brightness when the setting changes.
  // frontlightSuppressed tracks the double-press toggle state (off while true).
  // An explicit settings change always clears the suppressed state.
  static uint8_t lastFrontlight = SETTINGS.frontlightBrightness;
  static bool frontlightSuppressed = false;
  if (SETTINGS.frontlightBrightness != lastFrontlight) {
    lastFrontlight = SETTINGS.frontlightBrightness;
    frontlightSuppressed = false;
    HalFrontlight::setBrightness(lastFrontlight);
  }

  // Power button double-press toggles frontlight between 0% and the configured brightness.
  // Lookahead: the first release is parked for DOUBLE_PRESS_MS. If a second press arrives
  // in time, the frontlight toggles and neither release reaches the activity (no page turn).
  // If the window expires, the parked release is replayed so the activity sees it normally.
  static constexpr unsigned long DOUBLE_PRESS_MS = 300;
  static unsigned long pendingPowerReleaseMs = 0;  // non-zero = first release parked

  if (gpio.wasReleased(HalGPIO::BTN_POWER)) {
    const unsigned long now = millis();
    if (pendingPowerReleaseMs != 0 && now - pendingPowerReleaseMs <= DOUBLE_PRESS_MS) {
      // Second release within window: double-press confirmed — toggle frontlight
      frontlightSuppressed = !frontlightSuppressed;
      HalFrontlight::setBrightness(frontlightSuppressed ? 0 : SETTINGS.frontlightBrightness);
      LOG_DBG("FLT", "Double-press: frontlight %s", frontlightSuppressed ? "off" : "restored");
      pendingPowerReleaseMs = 0;  // second release already consumed (gpio.update cleared events)
    } else {
      // First release: park it, hide from activity this tick
      gpio.consumeRelease(HalGPIO::BTN_POWER);
      pendingPowerReleaseMs = now;
    }
  }

  // Replay parked single-press once the double-press window has expired
  if (pendingPowerReleaseMs != 0 && millis() - pendingPowerReleaseMs > DOUBLE_PRESS_MS) {
    gpio.forceRelease(HalGPIO::BTN_POWER);
    pendingPowerReleaseMs = 0;
  }

  if (Serial && millis() - lastMemPrint >= 10000) {
    LOG_INF("MEM", "Free: %d bytes, Total: %d bytes, Min Free: %d bytes, MaxAlloc: %d bytes", ESP.getFreeHeap(),
            ESP.getHeapSize(), ESP.getMinFreeHeap(), ESP.getMaxAllocHeap());
    lastMemPrint = millis();
  }

  // Handle incoming serial commands,
  // nb: we use logSerial from logging to avoid deprecation warnings
  if (logSerial.available() > 0) {
    String line = logSerial.readStringUntil('\n');
    if (line.startsWith("CMD:")) {
      String cmd = line.substring(4);
      cmd.trim();
      if (cmd == "SCREENSHOT") {
        logSerial.printf("SCREENSHOT_START:%d\n", HalDisplay::BUFFER_SIZE);
        uint8_t* buf = display.getFrameBuffer();
        logSerial.write(buf, HalDisplay::BUFFER_SIZE);
        logSerial.printf("SCREENSHOT_END\n");
      }
    }
  }

  // Check for any user activity (button press or release) or active background work
  static unsigned long lastActivityTime = millis();
  if (gpio.wasAnyPressed() || gpio.wasAnyReleased() || activityManager.preventAutoSleep()) {
    lastActivityTime = millis();         // Reset inactivity timer
    powerManager.setPowerSaving(false);  // Restore normal CPU frequency on user activity
  }

  const unsigned long sleepTimeoutMs = SETTINGS.getSleepTimeoutMs();
  if (millis() - lastActivityTime >= sleepTimeoutMs) {
    LOG_DBG("SLP", "Auto-sleep triggered after %lu ms of inactivity", sleepTimeoutMs);
    enterDeepSleep();
    // This should never be hit as `enterDeepSleep` calls esp_deep_sleep_start
    return;
  }

  if (gpio.isPressed(HalGPIO::BTN_POWER) && gpio.getHeldTime() > SETTINGS.getPowerButtonDuration()) {
    enterDeepSleep();
    // This should never be hit as `enterDeepSleep` calls esp_deep_sleep_start
    return;
  }

  // Refresh the battery icon when USB is plugged or unplugged.
  // Placed after sleep guards so we never queue a render that won't be processed.
  if (gpio.wasUsbStateChanged()) {
    activityManager.requestUpdate();
  }

  const unsigned long activityStartTime = millis();
  activityManager.loop();
  const unsigned long activityDuration = millis() - activityStartTime;

  const unsigned long loopDuration = millis() - loopStartTime;
  if (loopDuration > maxLoopDuration) {
    maxLoopDuration = loopDuration;
    if (maxLoopDuration > 50) {
      LOG_DBG("LOOP", "New max loop duration: %lu ms (activity: %lu ms)", maxLoopDuration, activityDuration);
    }
  }

  // Add delay at the end of the loop to prevent tight spinning
  // When an activity requests skip loop delay (e.g., webserver running), use yield() for faster response
  // Otherwise, use longer delay to save power
  if (activityManager.skipLoopDelay()) {
    powerManager.setPowerSaving(false);  // Make sure we're at full performance when skipLoopDelay is requested
    yield();                             // Give FreeRTOS a chance to run tasks, but return immediately
  } else {
    if (millis() - lastActivityTime >= HalPowerManager::IDLE_POWER_SAVING_MS) {
      // If we've been inactive for a while, increase the delay to save power
      powerManager.setPowerSaving(true);  // Lower CPU frequency after extended inactivity
      delay(50);
    } else {
      // Short delay to prevent tight loop while still being responsive
      delay(10);
    }
  }
}

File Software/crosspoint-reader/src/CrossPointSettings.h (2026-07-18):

#pragma once
#include <HalStorage.h>

#include <cstdint>
#include <iosfwd>

class CrossPointSettings {
 private:
  // Private constructor for singleton
  CrossPointSettings() = default;

  // Static instance
  static CrossPointSettings instance;

 public:
  // Delete copy constructor and assignment
  CrossPointSettings(const CrossPointSettings&) = delete;
  CrossPointSettings& operator=(const CrossPointSettings&) = delete;

  enum SLEEP_SCREEN_MODE {
    DARK = 0,
    LIGHT = 1,
    CUSTOM = 2,
    COVER = 3,
    BLANK = 4,
    COVER_CUSTOM = 5,
    SLEEP_SCREEN_MODE_COUNT
  };
  enum SLEEP_SCREEN_COVER_MODE { FIT = 0, CROP = 1, SLEEP_SCREEN_COVER_MODE_COUNT };
  enum SLEEP_SCREEN_COVER_FILTER {
    NO_FILTER = 0,
    BLACK_AND_WHITE = 1,
    INVERTED_BLACK_AND_WHITE = 2,
    SLEEP_SCREEN_COVER_FILTER_COUNT
  };

  // Status bar enum - legacy
  enum STATUS_BAR_MODE {
    NONE = 0,
    NO_PROGRESS = 1,
    FULL = 2,
    BOOK_PROGRESS_BAR = 3,
    ONLY_BOOK_PROGRESS_BAR = 4,
    CHAPTER_PROGRESS_BAR = 5,
    STATUS_BAR_MODE_COUNT
  };
  enum STATUS_BAR_PROGRESS_BAR {
    BOOK_PROGRESS = 0,
    CHAPTER_PROGRESS = 1,
    HIDE_PROGRESS = 2,
    STATUS_BAR_PROGRESS_BAR_COUNT
  };
  enum STATUS_BAR_PROGRESS_BAR_THICKNESS {
    PROGRESS_BAR_THIN = 0,
    PROGRESS_BAR_NORMAL = 1,
    PROGRESS_BAR_THICK = 2,
    STATUS_BAR_PROGRESS_BAR_THICKNESS_COUNT
  };
  enum STATUS_BAR_TITLE { BOOK_TITLE = 0, CHAPTER_TITLE = 1, HIDE_TITLE = 2, STATUS_BAR_TITLE_COUNT };

  enum ORIENTATION {
    PORTRAIT = 0,       // 480x800 logical coordinates (current default)
    LANDSCAPE_CW = 1,   // 800x480 logical coordinates, rotated 180° (swap top/bottom)
    INVERTED = 2,       // 480x800 logical coordinates, inverted
    LANDSCAPE_CCW = 3,  // 800x480 logical coordinates, native panel orientation
    ORIENTATION_COUNT
  };

  // Front button layout options (legacy)
  // Default: Back, Confirm, Left, Right
  // Swapped: Left, Right, Back, Confirm
  enum FRONT_BUTTON_LAYOUT {
    BACK_CONFIRM_LEFT_RIGHT = 0,
    LEFT_RIGHT_BACK_CONFIRM = 1,
    LEFT_BACK_CONFIRM_RIGHT = 2,
    BACK_CONFIRM_RIGHT_LEFT = 3,
    FRONT_BUTTON_LAYOUT_COUNT
  };

  // Front button hardware identifiers (for remapping)
  enum FRONT_BUTTON_HARDWARE {
    FRONT_HW_BACK = 0,
    FRONT_HW_CONFIRM = 1,
    FRONT_HW_LEFT = 2,
    FRONT_HW_RIGHT = 3,
    FRONT_BUTTON_HARDWARE_COUNT
  };


  // Font family options
  enum FONT_FAMILY { BOOKERLY = 0, NOTOSANS = 1, OPENDYSLEXIC = 2, FONT_FAMILY_COUNT };
  // Font size options
  enum FONT_SIZE { SMALL = 0, MEDIUM = 1, LARGE = 2, EXTRA_LARGE = 3, FONT_SIZE_COUNT };
  enum LINE_COMPRESSION { TIGHT = 0, NORMAL = 1, WIDE = 2, LINE_COMPRESSION_COUNT };
  enum PARAGRAPH_ALIGNMENT {
    JUSTIFIED = 0,
    LEFT_ALIGN = 1,
    CENTER_ALIGN = 2,
    RIGHT_ALIGN = 3,
    BOOK_STYLE = 4,
    PARAGRAPH_ALIGNMENT_COUNT
  };

  // Auto-sleep timeout options (in minutes)
  enum SLEEP_TIMEOUT {
    SLEEP_1_MIN = 0,
    SLEEP_5_MIN = 1,
    SLEEP_10_MIN = 2,
    SLEEP_15_MIN = 3,
    SLEEP_30_MIN = 4,
    SLEEP_TIMEOUT_COUNT
  };

  // E-ink refresh frequency (pages between full refreshes)
  enum REFRESH_FREQUENCY {
    REFRESH_1 = 0,
    REFRESH_5 = 1,
    REFRESH_10 = 2,
    REFRESH_15 = 3,
    REFRESH_30 = 4,
    REFRESH_FREQUENCY_COUNT
  };

  // Short power button press actions
  enum SHORT_PWRBTN { IGNORE = 0, SLEEP = 1, PAGE_TURN = 2, SHORT_PWRBTN_COUNT };

  // Hide battery percentage
  enum HIDE_BATTERY_PERCENTAGE { HIDE_NEVER = 0, HIDE_READER = 1, HIDE_ALWAYS = 2, HIDE_BATTERY_PERCENTAGE_COUNT };

  // UI Theme
  enum UI_THEME { CLASSIC = 0, LYRA = 1, LYRA_3_COVERS = 2 };

  // Image rendering in EPUB reader
  enum IMAGE_RENDERING { IMAGES_DISPLAY = 0, IMAGES_PLACEHOLDER = 1, IMAGES_SUPPRESS = 2, IMAGE_RENDERING_COUNT };
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

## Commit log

2026-07-18 Add PCB layout image to README.md
2026-07-19 added build guide
    [LCSC_ESP32_EReader_BOM - Ereader_bom-2.csv]
2026-07-19 Update build guide with improved image description and clarify assembly instructions in README.md
2026-07-19 Fix typo in BOM link in Build Guide
